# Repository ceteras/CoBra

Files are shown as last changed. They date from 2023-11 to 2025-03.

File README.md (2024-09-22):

# CoBra

CoBra is a Z80 computer designed in 1986 at ITCI, a research center in Brasov, Romania.  

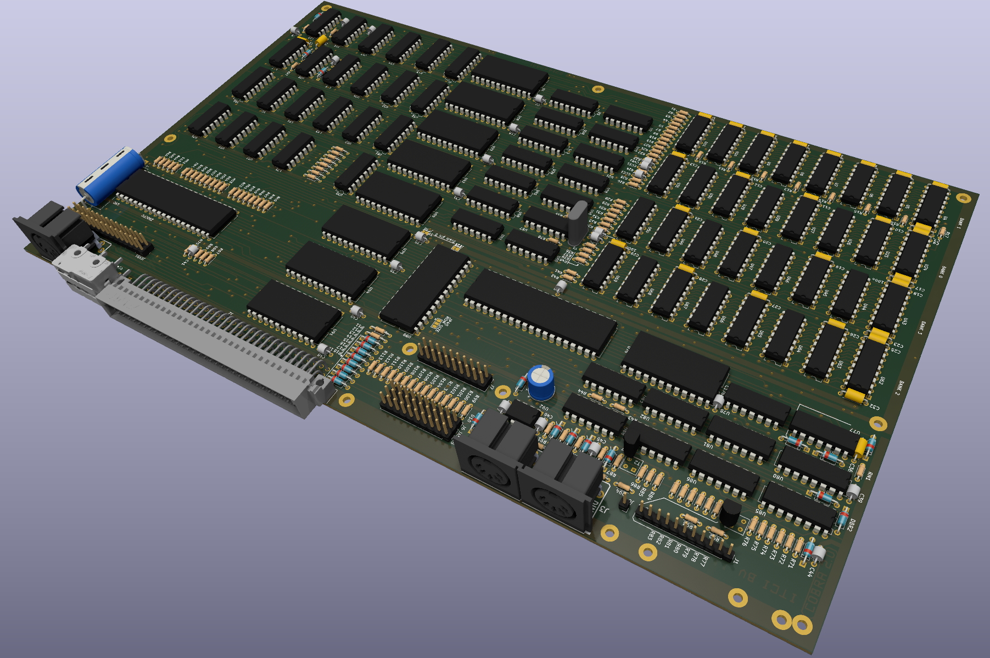
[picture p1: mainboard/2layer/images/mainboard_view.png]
CoBra mainboard


In its official version, its specs are:
- 3.5MHz Z80A CPU
- 64KB ram, made up of 4 banks of 8x 4116 chips each
- 2KB - 16KB ROM boot code (original firmware fits in 2K)
- 16KB ROM for the BASIC interpreter (8x 2716 or 4x 2732)
- 256 x 192 resolution ZX Spectrum video interface
- 58 keys keyboard, featuring 50 keys for ZX Spectrum mode plus 8 for CP/M
- i8272 floppy interface - on a daughter board (not included in the repo for now)
- RS232 port (bit-banged)
- joystick port
- 8 bit parallel port, input only, signals shared with the joystick interface
- extension port using a 3x32 pin DIN41612 connector

It's a two-in-one machine, it can be either a ZX Spectrum compatible or a CP/M machine.  
CoBra has three different memory maps: one for power-on, one for ZX Spectrum, and one for CP/M.  
The memory configuration change is done in software, using the bit 7 of the R register.  

On power-on, the memory map includes both ROMs, and RAM banks 0 and 1.  
Cobra boots from the small 2K ROM, it can display on the screen and copy code to RAM.  
Code can be copied from ROM for ZX Spectrum mode, and from the floppy interface for CP/M.  
Tape interface can also be an option, which should be great for development.  

After copying the code, it will switch the memory map to te desired architecture.  
ROMs are disabled now and execution continues from the 64KB of RAM.  

Many thanks to [cobrasov.com](https://cobrasov.com/CoBra%20Project/index.html), my main inspiration source in this endeavour.  
You can find out a lot about this incredible machine on the website, including many improvements made to the original boards by the community.  
Gerber files are also available there for these improved versions, all tested and working great!  

This repo is a "revival" approach, aiming to re-create the original computer in Kicad, adding only some minor tweaks.  
Current status: 
- the board is built (see bottom image), there were some pain points I should document here
- a floppy interface was also built, works with a modified BASIC (gerbers are Ver.1.2 on "Floppy" IF section on [cobrasov.com](https://cobrasov.com/CoBra%20Project/index.html).
- CP/M not possible to test yet, all versions I can get access to need a 80KB RAM upgrade.

Links:
- [2 Layer PCB project](https://github.com/ceteras/CoBra/tree/main/mainboard/2layer) - a 4 layer version is in the works too
- [Schematic in pdf format](https://github.com/ceteras/CoBra/blob/main/main.pdf)
- [Gerber files](https://github.com/ceteras/CoBra/tree/main/mainboard/2layer/kicad/fabrication)
- [Interactive BOM](https://github.com/ceteras/CoBra/blob/main/mainboard/2layer/kicad/bom/ibom.html)
- [A PAL encoder with S-Video connector](https://github.com/ceteras/CoBra/tree/main/s-video) - a draft, not tested yet
- [An USB keyboard adapter](https://github.com/ceteras/CoBra/tree/main/adapter/USB%20Keyboard) - this one is also not final, an experiment

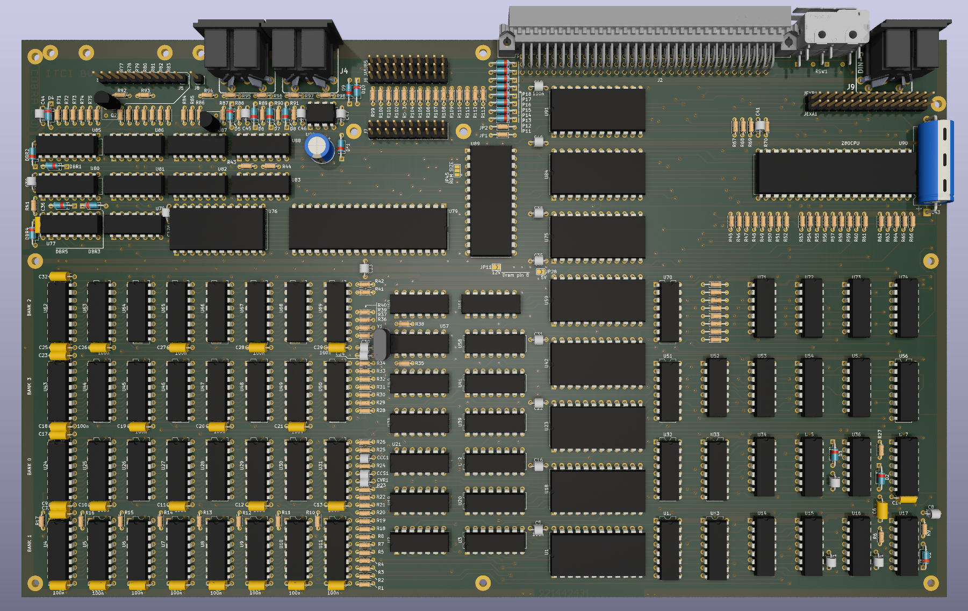
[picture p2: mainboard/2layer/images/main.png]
CoBra mainboard
 

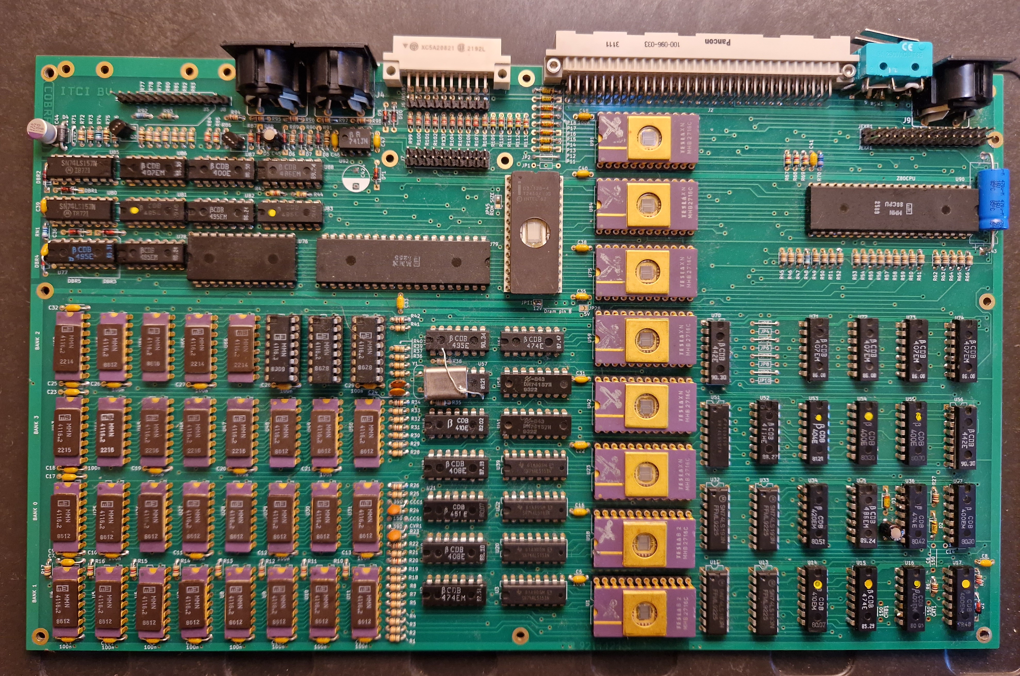
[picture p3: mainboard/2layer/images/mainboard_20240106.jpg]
Prototype


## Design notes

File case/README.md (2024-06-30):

# CoBra Case

The 3D modelling was done by [badrianiulian](https://github.com/badrianiulian).

The stl files can be used to order a 3D print, I chose PLA filament for my order, it came out ok, pictures below.

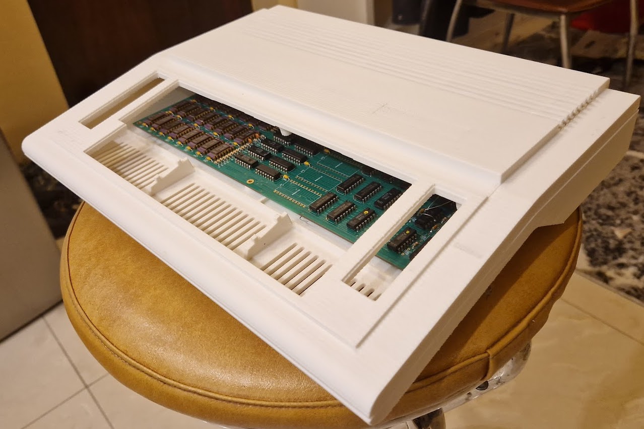
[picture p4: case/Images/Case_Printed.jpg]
  

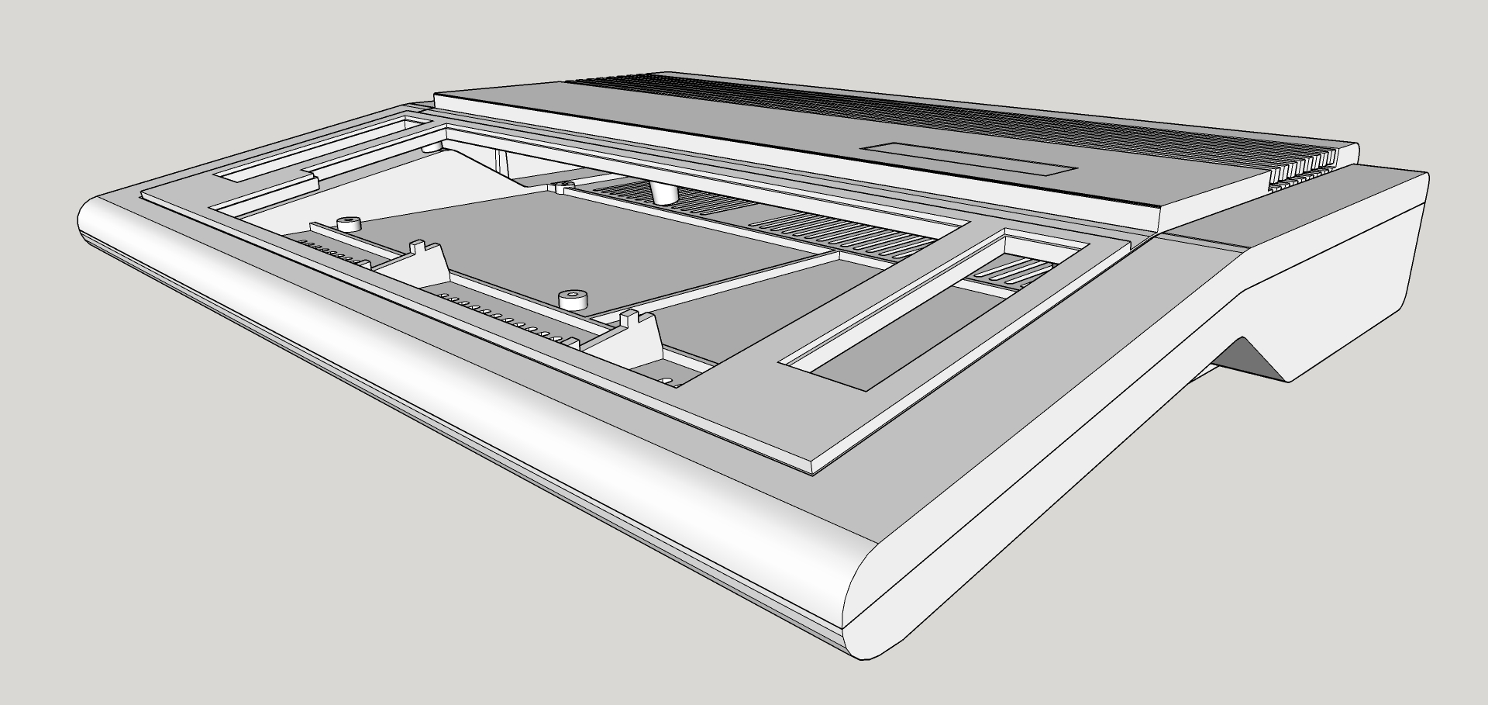
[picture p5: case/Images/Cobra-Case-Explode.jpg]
  

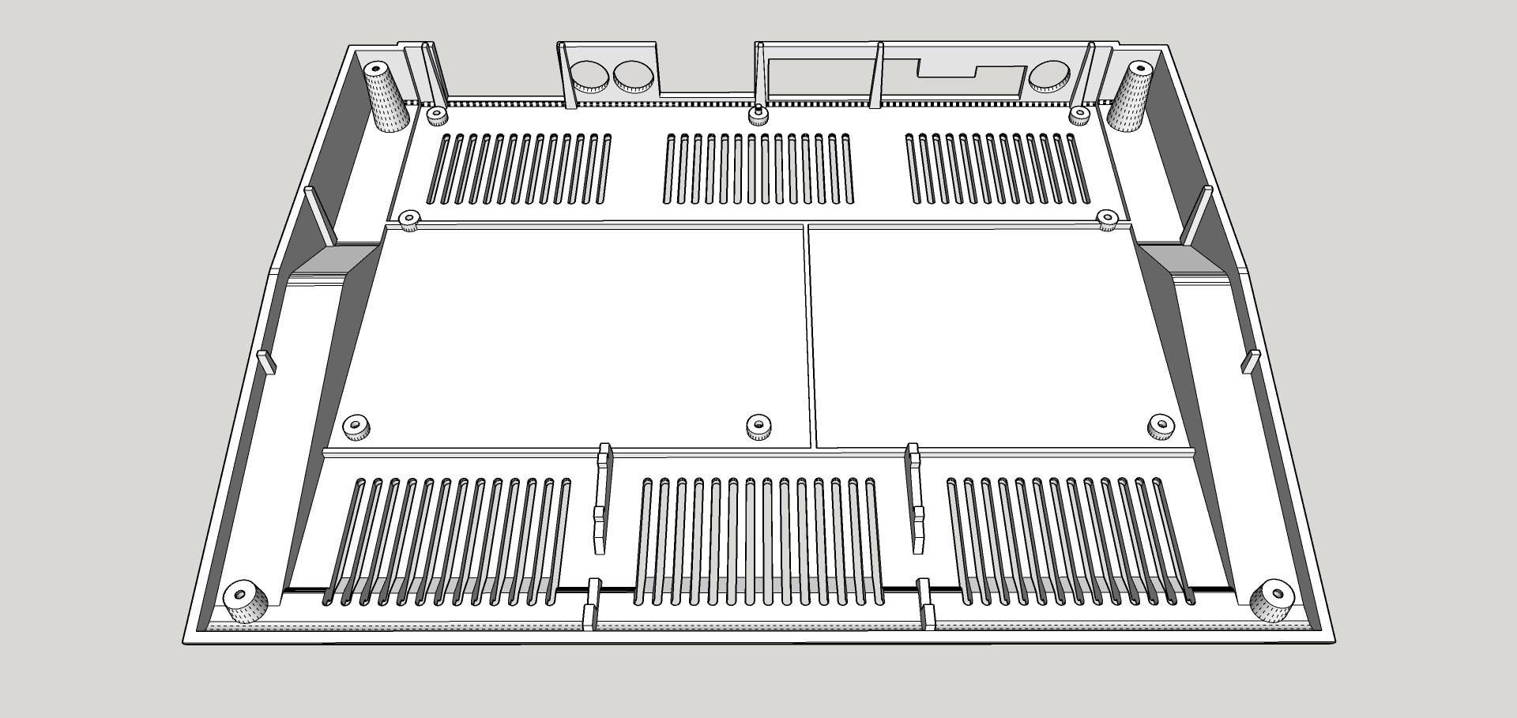
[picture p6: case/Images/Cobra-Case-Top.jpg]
  

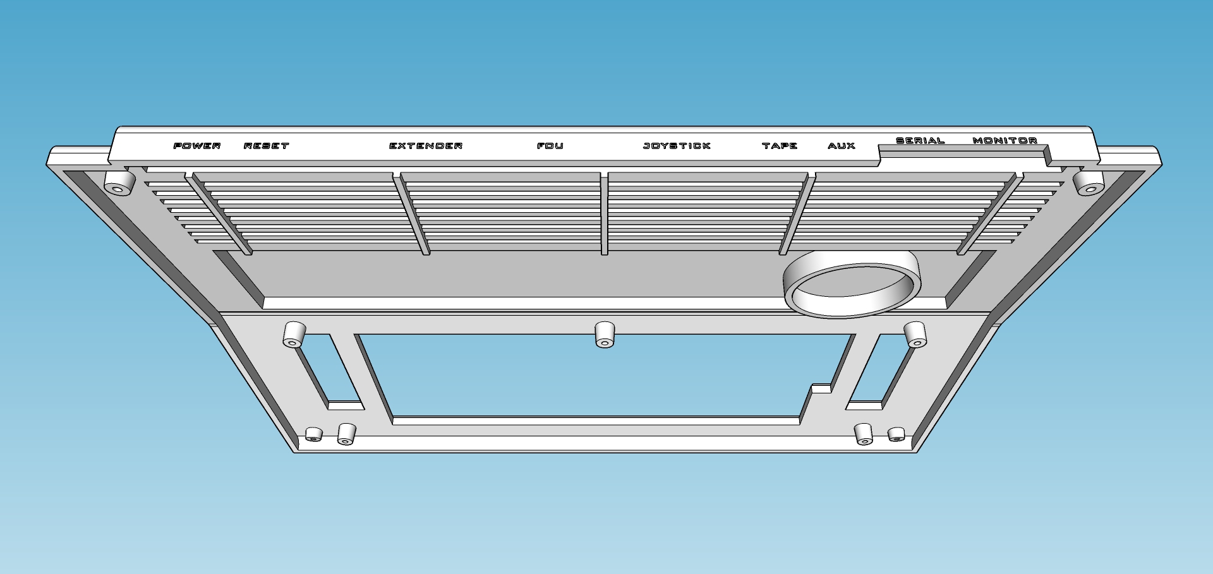
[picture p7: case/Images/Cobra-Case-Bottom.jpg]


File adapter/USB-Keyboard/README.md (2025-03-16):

# USB Keyboard Adapter (experimental)

Based on RP2040 Zero, emulates the CoBra switch matrix keyboard. 

The USB keyboard is connected to RP2040 USB port. Key codes are decoded and translated to an 8 byte array.
RP2040 reads the matrix column bus (KC[8..15] connected to A[8..15] through diodes) and sends the data  
corresponding to each key pressedi, from the array to the KR[0..5] bus.

Inputs to RP2040 are pulled high to 3.3V, so in theory this should be safe, as the 5V A[8..15] bus is behind reverse  
polarized diodes.  
Outputs are pulled high to 5V on the CoBra mainboard, hence the schottky diodes, for protection.
The keyboard input is an 8255 and its input voltage thresholds are safe for 3.3V logic (minimum 2V for input "1").

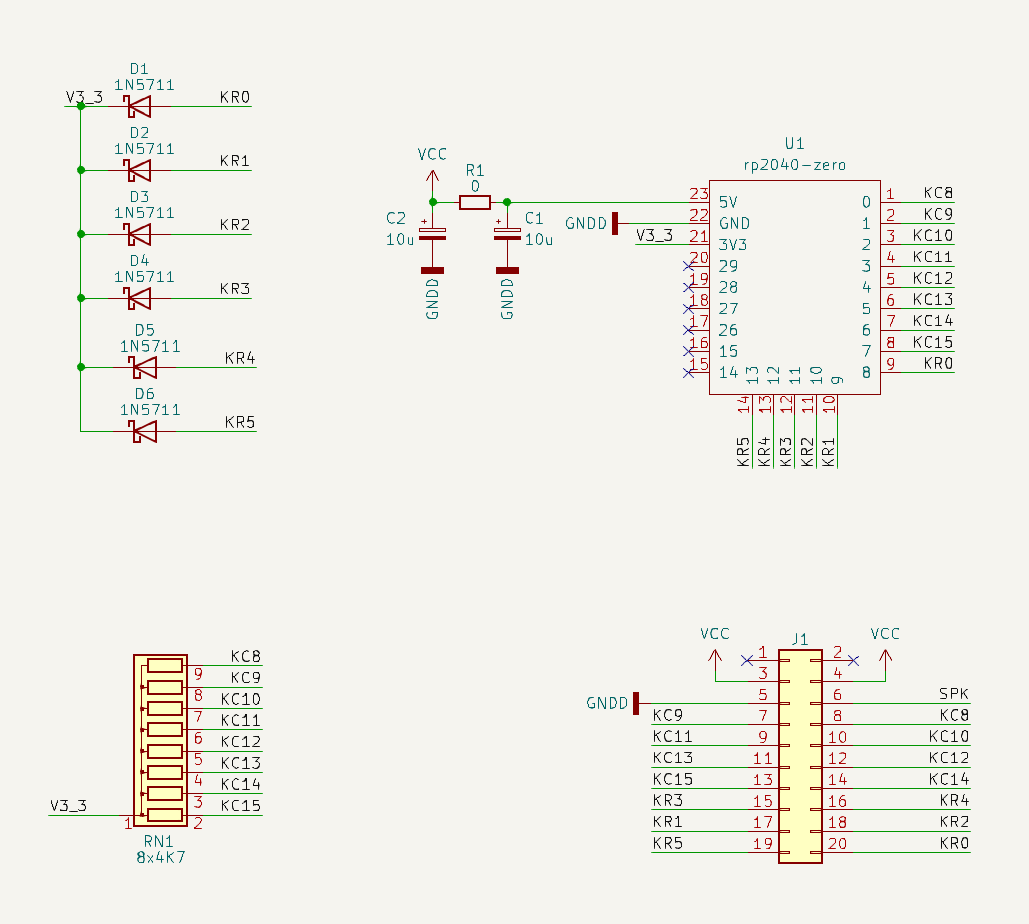
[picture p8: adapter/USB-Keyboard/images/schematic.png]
Adapter schematic


Key mapping:
- ALT / ALT gr - Symbol Shift
- GUI (Win key) - Caps Shift
- Cursor keys - CS + 5,6,7,8
- Backspace - CS + 0
- Insert - CS + 1 (edit)
- Application menu key - SS + X (pound)
- all symbols on a US keyboard [{]};:'"\|,<.>/?!@#$%^&*()_-+=   
  are mapped to their coreesponding CoBra key combinations  
  eg ")" - SS + 9, "~" - Extended mode + SS + A

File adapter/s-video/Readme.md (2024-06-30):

# S-Video Adapter for CoBra

Work in progress, untested.

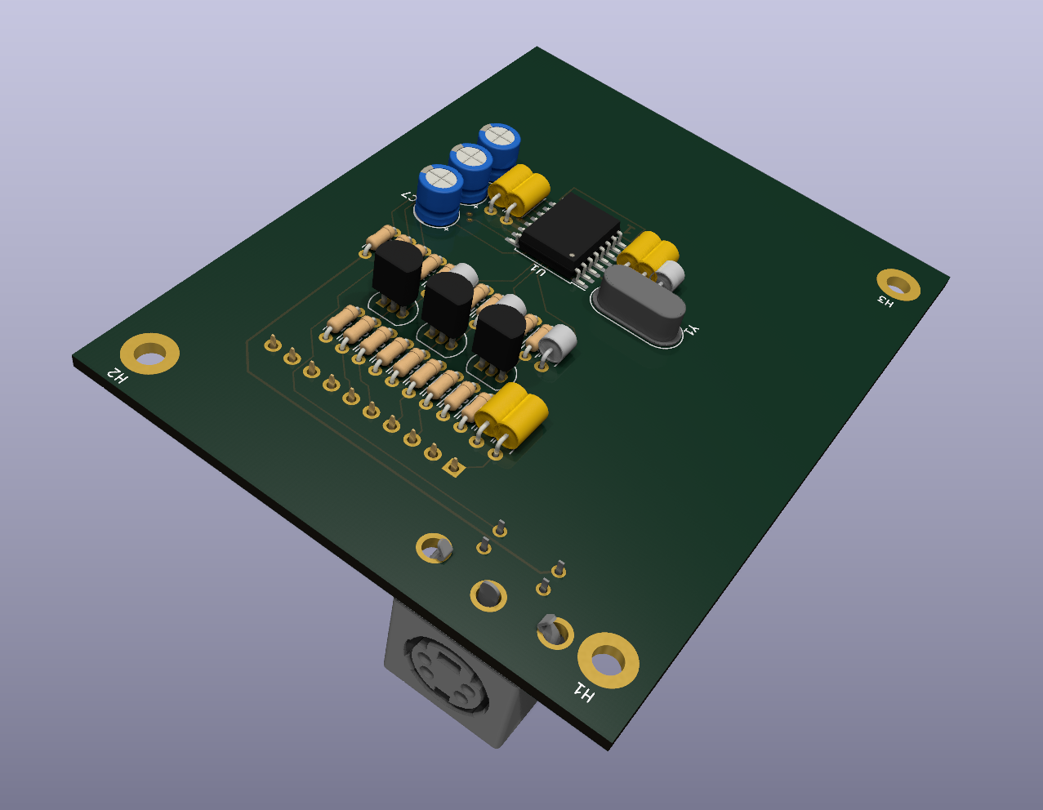
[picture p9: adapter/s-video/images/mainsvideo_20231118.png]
S-Video Adapter


This board is intended to connect to CoBra's video connector (J1).
It converts RGBI to PAL S-Video signals.

The schematic is inspired by [DonSuperfo's](https://github.com/DonSuperfo) [Superfo-Harlequin-128](https://github.com/DonSuperfo/Superfo-Harlequin-128).

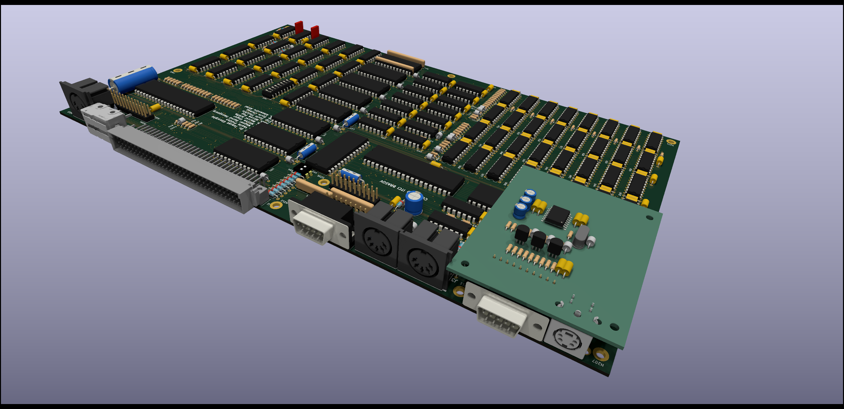
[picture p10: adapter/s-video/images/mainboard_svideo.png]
S-Video Adapter Installed


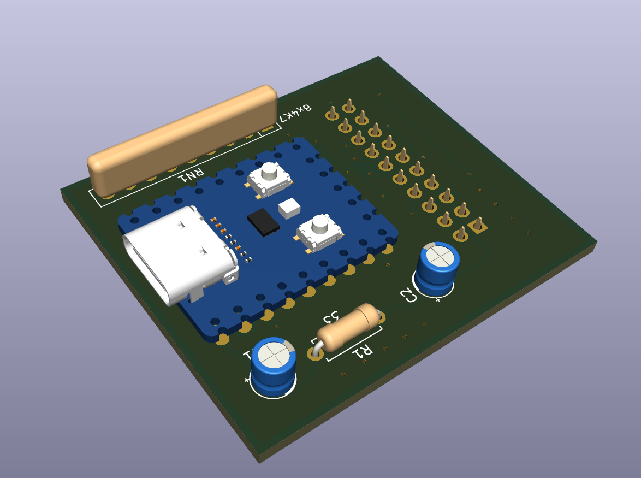
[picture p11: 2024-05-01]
adapter/USB-Keyboard/images/CObra_USB_KB_01.png

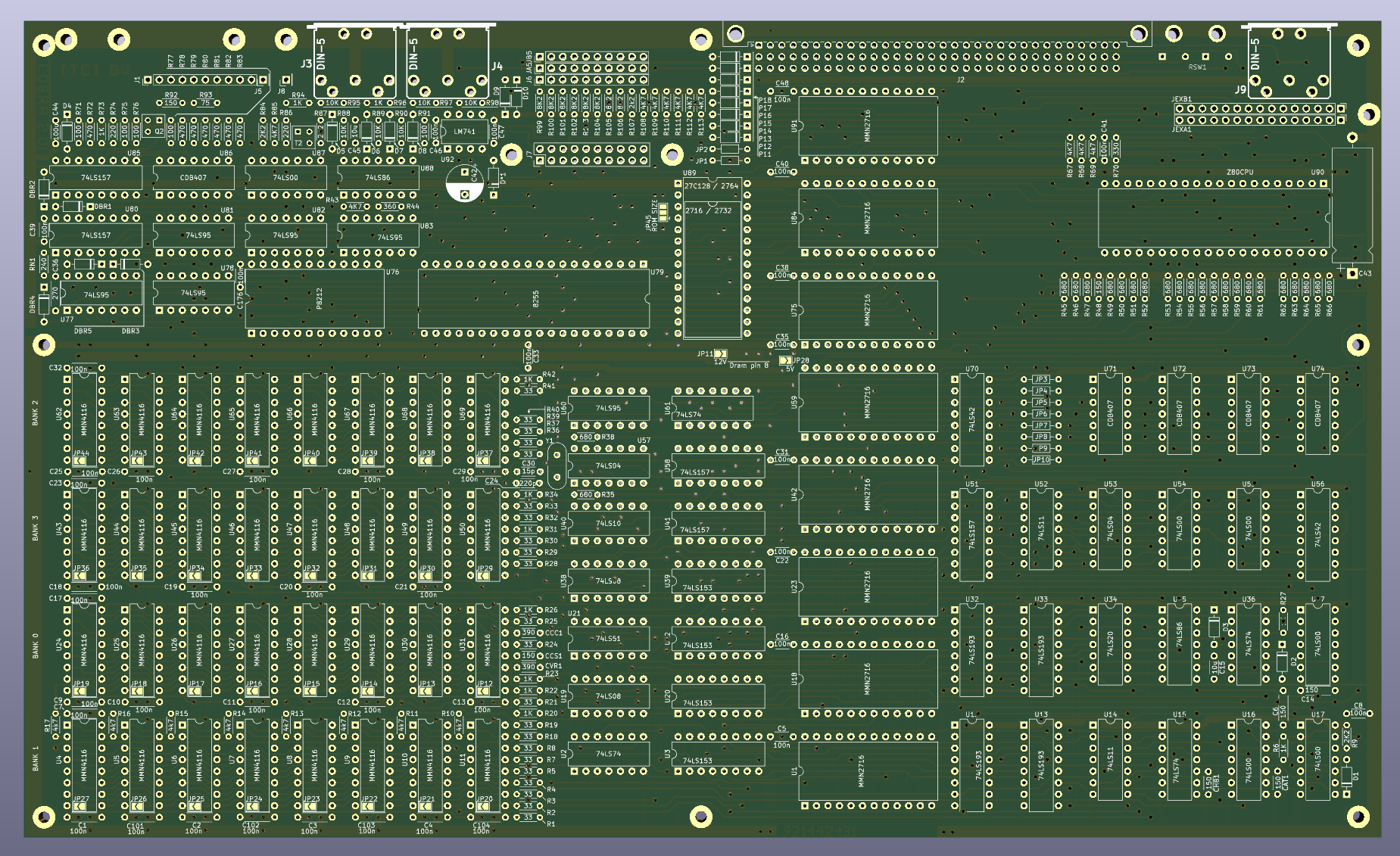
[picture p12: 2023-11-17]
mainboard/2layer/images/mainboard_no_tht.png

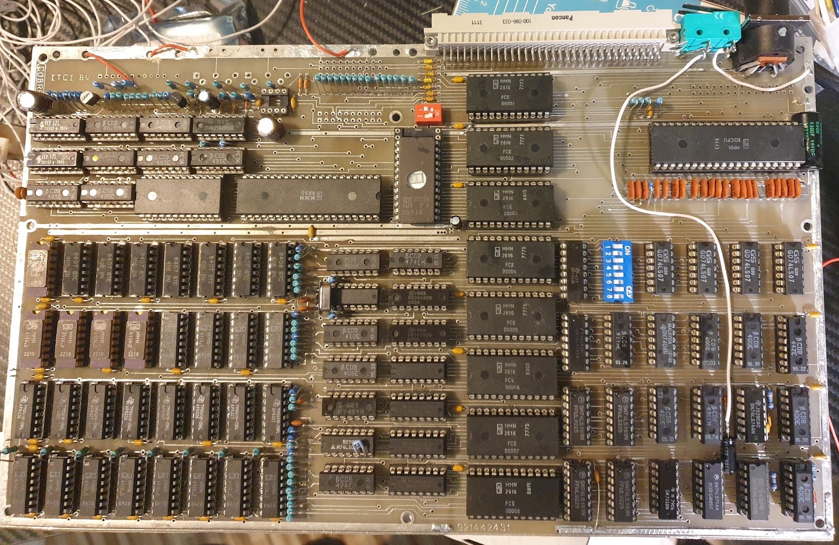
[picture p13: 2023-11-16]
mainboard/2layer/images/prototype.jpg

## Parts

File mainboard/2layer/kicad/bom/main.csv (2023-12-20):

Id | Designator | Footprint | Quantity | Designation | Supplier and ref
1 | R12,R69,R14,R17,R16,R15,R11,R13,R10 | R_Axial_DIN0204_L3.6mm_D1.6mm_P5.08mm_Horizontal | 9 | 4k7
2 | R68,R67,R43,R85,R108,R109,R110,R111,R112,R113 | R_Axial_DIN0204_L3.6mm_D1.6mm_P5.08mm_Horizontal | 10 | 4K7
3 | D2,D1,D3,D4,DBR1,DBR5,DBR4,DBR2,D6,D7,D9,D10,DBR3,P11,P12,P13,P14,P15,P16,P17,P18,D*1,D8 | D_DO-35_SOD27_P7.62mm_Horizontal | 23 | 1N4148
4 | C41,C16,C22,C31,C38,C40,C5,C48,C35,C39,C46,C176,C8,C47,C33 | C_THT_508_254 | 15 | 100n
5 | C23,C7,C32,C12,C13,C25,C21,C20,C26,C11,C29,C28,C27,C19,C10,C9,C2,C1,C3,C4,C17,C18,C104,C102,C101,C103 | C_THT_762_254 | 26 | 100n
6 | U86,U74,U73,U72,U71 | DIP-14_W7.62mm | 5 | CDB407
7 | U78,U77,U83,U81,U60,U82 | DIP-14_W7.62mm | 6 | 74LS95
8 | U80,U51,U41,U85,U58 | DIP-16_W7.62mm | 5 | 74LS157
9 | U88,U35 | DIP-14_W7.62mm | 2 | 74LS86
10 | U37,U17,U16,U54,U55,U87 | DIP-14_W7.62mm | 6 | 74LS00
11 | U52 | DIP-14_W7.62mm | 1 | 74LS11
12 | U36,U15,U2,U61 | DIP-14_W7.62mm | 4 | 74LS74
13 | U14,U40 | DIP-14_W7.62mm | 2 | 74LS10
14 | U76 | DIP-24_W15.24mm | 1 | P8212
15 | U90 | DIP-40_W15.24mm | 1 | Z80CPU
16 | U75,U59,U42,U18,U23,U1,U84,U91 | DIP-24_W15.24mm | 8 | MMN2716
17 | U68,U69,U67,U66,U64,U63,U46,U62,U50,U48,U45,U49,U47,U8,U31,U25,U10,U6,U65,U29,U9,U26,U43,U24,U44,U28,U30,U7,U27,U4,U11,U5 | DIP-16_W7.62mm | 32 | MMN4116
18 | U70,U56 | DIP-16_W7.62mm | 2 | 74LS42
19 | U57,U53 | DIP-14_W7.62mm | 2 | 74LS04
20 | U38,U19 | DIP-14_W7.62mm | 2 | 74LS08
21 | U33,U32,U12,U13 | DIP-16_W7.62mm | 4 | 74LS193
22 | U3,U20,U39,U22 | DIP-16_W7.62mm | 4 | 74LS153
23 | U21 | DIP-14_W7.62mm | 1 | 74LS51
24 | R54,R50,R66,R63,R55,R65,R62,R58,R51,R64,R61,R60,R56,R49,R46,R57,R45,R47,R53,R52,R59,R35,R38 | R_Axial_DIN0204_L3.6mm_D1.6mm_P5.08mm_Horizontal | 23 | 680
25 | R48,R92 | R_Axial_DIN0204_L3.6mm_D1.6mm_P5.08mm_Horizontal | 2 | 150
26 | JP1,JP3,JP5,JP7,JP9 | R_Axial_DIN0204_L3.6mm_D1.6mm_P7.62mm_Horizontal | 5 | Jumper_NC_Small
27 | JP6,JP4,JP10,JP8,JP2 | R_Axial_DIN0204_L3.6mm_D1.6mm_P7.62mm_Horizontal | 5 | Jumper_NO_Small
28 | U89 | DIP-28_W15.24mm | 1 | 27C128
29 | U34 | DIP-14_W7.62mm | 1 | 74LS20
30 | R72,R78,R79,R80,R81,R82,R83 | R_Axial_DIN0204_L3.6mm_D1.6mm_P5.08mm_Horizontal | 7 | 470
31 | R74,R86 | R_Axial_DIN0204_L3.6mm_D1.6mm_P5.08mm_Horizontal | 2 | 220
32 | R75,R76,R77,R71,R91 | R_Axial_DIN0204_L3.6mm_D1.6mm_P5.08mm_Horizontal | 5 | 100
33 | R93 | R_Axial_DIN0204_L3.6mm_D1.6mm_P5.08mm_Horizontal | 1 | 75
34 | R22,R73,R20,R23,R31,R34,R42,R96,R26,R27,R94,R6 | R_Axial_DIN0204_L3.6mm_D1.6mm_P5.08mm_Horizontal | 12 | 1K
35 | R2,R3,R4,R5,R1,R7,R8,R18,R19,R21,R24,R25,R32,R33,R41,R28,R29,R30,R36,R37,R39,R40 | R_Axial_DIN0204_L3.6mm_D1.6mm_P5.08mm_Horizontal | 22 | 33
36 | R70 | R_Axial_DIN0204_L3.6mm_D1.6mm_P5.08mm_Horizontal | 1 | 330
37 | R44 | R_Axial_DIN0204_L3.6mm_D1.6mm_P5.08mm_Horizontal | 1 | 360
38 | C42 | CP_Radial_D8.0mm_P5.00mm | 1 | 220u
39 | RN1 | R_Axial_DIN0204_L3.6mm_D1.6mm_P5.08mm_Horizontal | 1 | 240
40 | C14,C6 | C_THT_762_254 | 2 | 150
41 | R88,R89,R90,R95,R97,R98 | R_Axial_DIN0204_L3.6mm_D1.6mm_P5.08mm_Horizontal | 6 | 10K
42 | R84,R87,R9 | R_Axial_DIN0204_L3.6mm_D1.6mm_P5.08mm_Horizontal | 3 | 2K2
43 | Q2 | TO-92-Cobra | 1 | 2N2219
44 | J3,J4,J9 | DIN-5 | 3 | DIN-5
45 | U92 | DIP-8_W7.62mm | 1 | LM741
46 | CAT1,CHB1,CCS1 | C_THT_508_254 | 3 | 150
47 | J1,J6,JA5,JB5 | PinHeader_1x10_P2.54mm_Vertical | 4 | Conn_01x10
48 | C43 | CP_Axial_L25.0mm_D9.0mm_P30.00mm_Horizontal | 1 | 1500uF
49 | C24 | C_THT_508_254 | 1 | 220p
50 | C30 | C_THT_508_254 | 1 | 15p
51 | Y1 | Crystal_HC18-U_Vertical | 1 | 14MHz
52 | C44 | C_THT_508_254 | 1 | 100u
53 | C15,C45 | C_THT_508_254 | 2 | 10u
54 | C36 | C_THT_762_254 | 1 | 270
55 | CCC1,CVR1 | C_THT_508_254 | 2 | 390
56 | R106,R99,R100,R101,R102,R103,R104,R105 | R_Axial_DIN0204_L3.6mm_D1.6mm_P5.08mm_Horizontal | 8 | 8K2
57 | U79 | DIP-40_W15.24mm | 1 | 8255
58 | R107 | R_Axial_DIN0204_L3.6mm_D1.6mm_P5.08mm_Horizontal | 1 | 2k2
59 | D5 | D_DO-35_SOD27_P7.62mm_Horizontal | 1 | 4V7
60 | J2 | DIN41612_R_3x32_Male_Horizontal_THT | 1 | C96ABC
61 | JP35,JP32,JP14,JP44,JP12,JP40,JP26,JP24,JP11,JP15,JP17,JP18,JP43,JP23,JP31,JP38,JP29,JP34,JP33,JP13,JP30,JP28,JP37,JP42,JP27,JP16,JP21,JP22,JP36,JP41,JP19,JP39,JP20,JP25 | SolderJumper-2_P1.3mm_Open_TrianglePad1.0x1.5mm | 34 | SolderJumper_2_Open
62 | J7 | PinHeader_2x10_P2.54mm_Vertical | 1 | Conn_02x10_Odd_Even_MountingPin
63 | T2 | TO-92-CobraRev | 1 | BC327
64 | JP45 | SolderJumper-3_P1.3mm_Open_Pad1.0x1.5mm | 1 | SolderJumper_3_Open
65 | JEXA1,JEXB1 | PinHeader_1x15_P2.54mm_Vertical | 2 | Conn_01x15
66 | RSW1 | Reset_Switch | 1 | ~
67 | J8 | PinHeader_1x01_P2.54mm_Vertical | 1 | Conn_01x01_Male
68 | J5 | PinHeader_1x01_P2.54mm_Vertical | 1 | Conn_01x01_Male

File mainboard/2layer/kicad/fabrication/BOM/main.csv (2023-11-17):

Id | Designator | Footprint | Quantity | Designation | Supplier and ref
1 | R12,R69,R14,R17,R16,R15,R11,R13,R10 | R_Axial_DIN0204_L3.6mm_D1.6mm_P5.08mm_Horizontal | 9 | 4k7
2 | R68,R67,R43,R85,R108,R109,R110,R111,R112,R113 | R_Axial_DIN0204_L3.6mm_D1.6mm_P5.08mm_Horizontal | 10 | 4K7
3 | D2,D1,D3,D4,DBR1,DBR5,DBR4,DBR2,D6,D7,D9,D10,DBR3,P11,P12,P13,P14,P15,P16,P17,P18,D*1,D8 | D_DO-35_SOD27_P7.62mm_Horizontal | 23 | 1N4148
4 | C41,C16,C22,C31,C38,C40,C5,C48,C35,C39,C46,C176,C8,C47,C33 | C_THT_508_254 | 15 | 100n
5 | C23,C7,C32,C12,C13,C25,C21,C20,C26,C11,C29,C28,C27,C19,C10,C9,C2,C1,C3,C4,C17,C18,C104,C102,C101,C103 | C_THT_762_254 | 26 | 100n
6 | U86,U74,U73,U72,U71 | DIP-14_W7.62mm | 5 | CDB407
7 | U78,U77,U83,U81,U60,U82 | DIP-14_W7.62mm | 6 | 74LS95
8 | U80,U51,U41,U85,U58 | DIP-16_W7.62mm | 5 | 74LS157
9 | U88,U35 | DIP-14_W7.62mm | 2 | 74LS86
10 | U37,U17,U16,U54,U55,U87 | DIP-14_W7.62mm | 6 | 74LS00
11 | U52,U14 | DIP-14_W7.62mm | 2 | 74LS11
12 | U36,U15,U2,U61 | DIP-14_W7.62mm | 4 | 74LS74
13 | U76 | DIP-24_W15.24mm | 1 | P8212
14 | U90 | DIP-40_W15.24mm | 1 | Z80CPU
15 | U75,U59,U42,U18,U23,U1,U84,U91 | DIP-24_W15.24mm | 8 | MMN2716
16 | U68,U69,U67,U66,U64,U63,U46,U62,U50,U48,U45,U49,U47,U8,U31,U25,U10,U6,U65,U29,U9,U26,U43,U24,U44,U28,U30,U7,U27,U4,U11,U5 | DIP-16_W7.62mm | 32 | MMN4116
17 | U70,U56 | DIP-16_W7.62mm | 2 | 74LS42
18 | U57,U53 | DIP-14_W7.62mm | 2 | 74LS04
19 | U38,U19 | DIP-14_W7.62mm | 2 | 74LS08
20 | U33,U32,U12,U13 | DIP-16_W7.62mm | 4 | 74LS193
21 | U3,U20,U39,U22 | DIP-16_W7.62mm | 4 | 74LS153
22 | U21 | DIP-14_W7.62mm | 1 | 74LS51
23 | U40 | DIP-14_W7.62mm | 1 | 74LS10
24 | R54,R50,R66,R63,R55,R65,R62,R58,R51,R64,R61,R60,R56,R49,R46,R57,R45,R47,R53,R52,R59,R35,R38 | R_Axial_DIN0204_L3.6mm_D1.6mm_P5.08mm_Horizontal | 23 | 680
25 | R48,R92 | R_Axial_DIN0204_L3.6mm_D1.6mm_P5.08mm_Horizontal | 2 | 150
26 | JP1,JP3,JP5,JP7,JP9 | R_Axial_DIN0204_L3.6mm_D1.6mm_P7.62mm_Horizontal | 5 | Jumper_NC_Small
27 | JP6,JP4,JP10,JP8,JP2 | R_Axial_DIN0204_L3.6mm_D1.6mm_P7.62mm_Horizontal | 5 | Jumper_NO_Small
28 | U89 | DIP-28_W15.24mm | 1 | 27C128
29 | U34 | DIP-14_W7.62mm | 1 | 74LS20
30 | R72,R78,R79,R80,R81,R82,R83 | R_Axial_DIN0204_L3.6mm_D1.6mm_P5.08mm_Horizontal | 7 | 470
31 | R74,R86 | R_Axial_DIN0204_L3.6mm_D1.6mm_P5.08mm_Horizontal | 2 | 220
32 | R75,R76,R77,R71,R91 | R_Axial_DIN0204_L3.6mm_D1.6mm_P5.08mm_Horizontal | 5 | 100
33 | R93 | R_Axial_DIN0204_L3.6mm_D1.6mm_P5.08mm_Horizontal | 1 | 75
34 | R22,R73,R20,R23,R31,R34,R42,R96,R26,R27,R94,R6 | R_Axial_DIN0204_L3.6mm_D1.6mm_P5.08mm_Horizontal | 12 | 1K
35 | H1 | cobra_3.0_front_copper | 1 | front_CU
36 | R2,R3,R4,R5,R1,R7,R8,R18,R19,R21,R24,R25,R32,R33,R41,R28,R29,R30,R36,R37,R39,R40 | R_Axial_DIN0204_L3.6mm_D1.6mm_P5.08mm_Horizontal | 22 | 33
37 | R70 | R_Axial_DIN0204_L3.6mm_D1.6mm_P5.08mm_Horizontal | 1 | 330
38 | R44 | R_Axial_DIN0204_L3.6mm_D1.6mm_P5.08mm_Horizontal | 1 | 360
39 | C42 | CP_Radial_D8.0mm_P5.00mm | 1 | 220u
40 | RN1 | R_Axial_DIN0204_L3.6mm_D1.6mm_P5.08mm_Horizontal | 1 | 240
41 | C14,C6 | C_THT_762_254 | 2 | 150
42 | R88,R89,R90,R95,R97,R98 | R_Axial_DIN0204_L3.6mm_D1.6mm_P5.08mm_Horizontal | 6 | 10K
43 | R84,R87,R9 | R_Axial_DIN0204_L3.6mm_D1.6mm_P5.08mm_Horizontal | 3 | 2K2
44 | Q2 | TO-92-Cobra | 1 | 2N2219
45 | J3,J4,J9 | DIN-5 | 3 | DIN-5
46 | U92 | DIP-8_W7.62mm | 1 | LM741
47 | CAT1,CHB1,CCS1 | C_THT_508_254 | 3 | 150
48 | J1,J6,JA5,JB5 | PinHeader_1x10_P2.54mm_Vertical | 4 | Conn_01x10
49 | C43 | CP_Axial_L25.0mm_D9.0mm_P30.00mm_Horizontal | 1 | 1500uF
50 | H15,H5,H16,H17,H18,H21,H22,H24,H25,H8,H2,H4,H6 | MountingHole_2.5mm_Pad | 13 | MountingHole_Pad
51 | C24 | C_THT_508_254 | 1 | 220p
52 | C30 | C_THT_508_254 | 1 | 15p
53 | Y1 | Crystal_HC18-U_Vertical | 1 | 14MHz
54 | C44 | C_THT_508_254 | 1 | 100u
55 | H23,H7 | MountingHole_2.5mm_Pad | 2 | e
56 | H3 | cobra_3.0_back_copper | 1 | Back_CU
57 | C15,C45 | C_THT_508_254 | 2 | 10u
58 | C36 | C_THT_762_254 | 1 | 270
59 | CCC1,CVR1 | C_THT_508_254 | 2 | 390
60 | R106,R99,R100,R101,R102,R103,R104,R105 | R_Axial_DIN0204_L3.6mm_D1.6mm_P5.08mm_Horizontal | 8 | 8K2
61 | U79 | DIP-40_W15.24mm | 1 | 8255
62 | R107 | R_Axial_DIN0204_L3.6mm_D1.6mm_P5.08mm_Horizontal | 1 | 2k2
63 | D5 | D_DO-35_SOD27_P7.62mm_Horizontal | 1 | 4V7
64 | J2 | DIN41612_R_3x32_Male_Horizontal_THT | 1 | C96ABC
65 | JP35,JP32,JP14,JP44,JP12,JP40,JP26,JP24,JP11,JP15,JP17,JP18,JP43,JP23,JP31,JP38,JP29,JP34,JP33,JP13,JP30,JP28,JP37,JP42,JP27,JP16,JP21,JP22,JP36,JP41,JP19,JP39,JP20,JP25 | SolderJumper-2_P1.3mm_Open_TrianglePad1.0x1.5mm | 34 | SolderJumper_2_Open
66 | J7 | PinHeader_2x10_P2.54mm_Vertical | 1 | Conn_02x10_Odd_Even_MountingPin
67 | T2 | TO-92-CobraRev | 1 | BC327
68 | JP45 | SolderJumper-3_P1.3mm_Open_Pad1.0x1.5mm | 1 | SolderJumper_3_Open
69 | JEXA1,JEXB1 | PinHeader_1x15_P2.54mm_Vertical | 2 | Conn_01x15
70 | RSW1 | Reset_Switch | 1 | ~
71 | J8 | PinHeader_1x01_P2.54mm_Vertical | 1 | Conn_01x01_Male
72 | J5 | PinHeader_1x01_P2.54mm_Vertical | 1 | Conn_01x01_Male

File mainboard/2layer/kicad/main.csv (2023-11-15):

Reference | Value | Footprint | Datasheet
U79 | 8255 | Package_DIP:DIP-40_W15.24mm | http://aturing.umcs.maine.edu/~meadow/courses/cos335/Intel8255A.pdf
U53 | 74LS04 | Package_DIP:DIP-14_W7.62mm | http://www.ti.com/lit/gpn/sn74LS04
U54 | 74LS00 | Package_DIP:DIP-14_W7.62mm | http://www.ti.com/lit/gpn/sn74ls00
U35 | 74LS86 | Package_DIP:DIP-14_W7.62mm | 74xx/74ls86.pdf
C33 | 100n | Capacitor_THT:C_Rect_L4.6mm_W2.0mm_P2.50mm_MKS02_FKP02 | ~
R99 | 8K2 |  | ~
R100 | 8K2 |  | ~
R101 | 8K2 |  | ~
R102 | 8K2 |  | ~
R103 | 8K2 |  | ~
R104 | 8K2 |  | ~
R105 | 8K2 |  | ~
R106 | 8K2 |  | ~
U90 | Z80CPU | Package_DIP:DIP-40_W15.24mm | www.zilog.com/manage_directlink.php?filepath=docs/z80/um0080
C41 | 100n | Capacitor_THT:C_Rect_L7.0mm_W2.0mm_P5.00mm | ~
U73 | CDB407 | Package_DIP:DIP-14_W7.62mm_LongPads
U71 | CDB407 | Package_DIP:DIP-14_W7.62mm_LongPads
U74 | CDB407 | Package_DIP:DIP-14_W7.62mm_LongPads
R70 | 330 | Resistor_THT:R_Axial_DIN0204_L3.6mm_D1.6mm_P5.08mm_Horizontal | ~
R56 | 680 | Resistor_THT:R_Axial_DIN0204_L3.6mm_D1.6mm_P5.08mm_Horizontal | ~
R57 | 680 | Resistor_THT:R_Axial_DIN0204_L3.6mm_D1.6mm_P5.08mm_Horizontal | ~
R58 | 680 | Resistor_THT:R_Axial_DIN0204_L3.6mm_D1.6mm_P5.08mm_Horizontal | ~
R59 | 680 | Resistor_THT:R_Axial_DIN0204_L3.6mm_D1.6mm_P5.08mm_Horizontal | ~
R60 | 680 | Resistor_THT:R_Axial_DIN0204_L3.6mm_D1.6mm_P5.08mm_Horizontal | ~
R52 | 680 | Resistor_THT:R_Axial_DIN0204_L3.6mm_D1.6mm_P5.08mm_Horizontal | ~
R61 | 680 | Resistor_THT:R_Axial_DIN0204_L3.6mm_D1.6mm_P5.08mm_Horizontal | ~
R62 | 680 | Resistor_THT:R_Axial_DIN0204_L3.6mm_D1.6mm_P5.08mm_Horizontal | ~
R63 | 680 | Resistor_THT:R_Axial_DIN0204_L3.6mm_D1.6mm_P5.08mm_Horizontal | ~
R64 | 680 | Resistor_THT:R_Axial_DIN0204_L3.6mm_D1.6mm_P5.08mm_Horizontal | ~
R65 | 680 | Resistor_THT:R_Axial_DIN0204_L3.6mm_D1.6mm_P5.08mm_Horizontal | ~
R66 | 680 | Resistor_THT:R_Axial_DIN0204_L3.6mm_D1.6mm_P5.08mm_Horizontal | ~
R51 | 680 | Resistor_THT:R_Axial_DIN0204_L3.6mm_D1.6mm_P5.08mm_Horizontal | ~
R55 | 680 | Resistor_THT:R_Axial_DIN0204_L3.6mm_D1.6mm_P5.08mm_Horizontal | ~
R50 | 680 | Resistor_THT:R_Axial_DIN0204_L3.6mm_D1.6mm_P5.08mm_Horizontal | ~
R45 | 680 | Resistor_THT:R_Axial_DIN0204_L3.6mm_D1.6mm_P5.08mm_Horizontal | ~
R53 | 680 | Resistor_THT:R_Axial_DIN0204_L3.6mm_D1.6mm_P5.08mm_Horizontal | ~
R54 | 680 | Resistor_THT:R_Axial_DIN0204_L3.6mm_D1.6mm_P5.08mm_Horizontal | ~
R47 | 680 | Resistor_THT:R_Axial_DIN0204_L3.6mm_D1.6mm_P5.08mm_Horizontal | ~
R46 | 680 | Resistor_THT:R_Axial_DIN0204_L3.6mm_D1.6mm_P5.08mm_Horizontal | ~
R48 | 680 | Resistor_THT:R_Axial_DIN0204_L3.6mm_D1.6mm_P5.08mm_Horizontal | ~
R49 | 680 | Resistor_THT:R_Axial_DIN0204_L3.6mm_D1.6mm_P5.08mm_Horizontal | ~
R68 | 680 | Resistor_THT:R_Axial_DIN0204_L3.6mm_D1.6mm_P5.08mm_Horizontal | ~
R67 | 680 | Resistor_THT:R_Axial_DIN0204_L3.6mm_D1.6mm_P5.08mm_Horizontal | ~
R69 | 4k7 | Resistor_THT:R_Axial_DIN0204_L3.6mm_D1.6mm_P5.08mm_Horizontal | ~
R10 | 4k7 | Resistor_THT:R_Axial_DIN0204_L3.6mm_D1.6mm_P5.08mm_Horizontal | ~
R11 | 4k7 | Resistor_THT:R_Axial_DIN0204_L3.6mm_D1.6mm_P5.08mm_Horizontal | ~
R12 | 4k7 | Resistor_THT:R_Axial_DIN0204_L3.6mm_D1.6mm_P5.08mm_Horizontal | ~
R13 | 4k7 | Resistor_THT:R_Axial_DIN0204_L3.6mm_D1.6mm_P5.08mm_Horizontal | ~
R14 | 4k7 | Resistor_THT:R_Axial_DIN0204_L3.6mm_D1.6mm_P5.08mm_Horizontal | ~
R15 | 4k7 | Resistor_THT:R_Axial_DIN0204_L3.6mm_D1.6mm_P5.08mm_Horizontal | ~
R16 | 4k7 | Resistor_THT:R_Axial_DIN0204_L3.6mm_D1.6mm_P5.08mm_Horizontal | ~
R17 | 4k7 | Resistor_THT:R_Axial_DIN0204_L3.6mm_D1.6mm_P5.08mm_Horizontal | ~
U72 | CDB407 | Package_DIP:DIP-14_W7.62mm_LongPads
SW_CS1 | SW_Push |  | ~
SW_A1 | SW_Push |  | ~
SW_Q1 | SW_Push |  | ~
SW_1 | SW_Push |  | ~
SW_0 | SW_Push |  | ~
SW_P1 | SW_Push |  | ~
SW_ENT1 | SW_Push |  | ~
SW_SP1 | SW_Push |  | ~
SW_Z1 | SW_Push |  | ~
SW_S1 | SW_Push |  | ~
SW_W1 | SW_Push |  | ~
SW_2 | SW_Push |  | ~
SW_9 | SW_Push |  | ~
SW_O1 | SW_Push |  | ~
SW_L1 | SW_Push |  | ~
SW_SS1 | SW_Push |  | ~
SW_X1 | SW_Push |  | ~
SW_D1 | SW_Push |  | ~
SW_E1 | SW_Push |  | ~
SW_3 | SW_Push |  | ~
SW_8 | SW_Push |  | ~
SW_I1 | SW_Push |  | ~
SW_K1 | SW_Push |  | ~
SW_M1 | SW_Push |  | ~
SW_C1 | SW_Push |  | ~
SW_F5 | SW_Push |  | ~
SW_R1 | SW_Push |  | ~
SW_4 | SW_Push |  | ~
SW_7 | SW_Push |  | ~
SW_U1 | SW_Push |  | ~
SW_J1 | SW_Push |  | ~
SW_N1 | SW_Push |  | ~
SW_V1 | SW_Push |  | ~
SW_G1 | SW_Push |  | ~
SW_T1 | SW_Push |  | ~
SW_5 | SW_Push |  | ~
SW_6 | SW_Push |  | ~
SW_Y1 | SW_Push |  | ~
SW_H1 | SW_Push |  | ~
SW_B1 | SW_Push |  | ~
D11 | 1N4148 | Diode_THT:D_DO-35_SOD27_P7.62mm_Horizontal | https://assets.nexperia.com/documents/data-sheet/1N4148_1N4448.pdf
D12 | 1N4148 | Diode_THT:D_DO-35_SOD27_P7.62mm_Horizontal | https://assets.nexperia.com/documents/data-sheet/1N4148_1N4448.pdf
D13 | 1N4148 | Diode_THT:D_DO-35_SOD27_P7.62mm_Horizontal | https://assets.nexperia.com/documents/data-sheet/1N4148_1N4448.pdf
D14 | 1N4148 | Diode_THT:D_DO-35_SOD27_P7.62mm_Horizontal | https://assets.nexperia.com/documents/data-sheet/1N4148_1N4448.pdf
D15 | 1N4148 | Diode_THT:D_DO-35_SOD27_P7.62mm_Horizontal | https://assets.nexperia.com/documents/data-sheet/1N4148_1N4448.pdf
D16 | 1N4148 | Diode_THT:D_DO-35_SOD27_P7.62mm_Horizontal | https://assets.nexperia.com/documents/data-sheet/1N4148_1N4448.pdf
D17 | 1N4148 | Diode_THT:D_DO-35_SOD27_P7.62mm_Horizontal | https://assets.nexperia.com/documents/data-sheet/1N4148_1N4448.pdf
D18 | 1N4148 | Diode_THT:D_DO-35_SOD27_P7.62mm_Horizontal | https://assets.nexperia.com/documents/data-sheet/1N4148_1N4448.pdf
R109 | R_Small |  | ~
R110 | R_Small |  | ~
R111 | R_Small |  | ~
R112 | R_Small |  | ~
R113 | R_Small |  | ~
SW_CTRL1 | SW_Push |  | ~
SW_NO_SCR1 | SW_Push |  | ~
SW_LF1 | SW_Push |  | ~
SW_ESC1 | SW_Push |  | ~
SW_F1 | SW_Push |  | ~
SW_F2 | SW_Push |  | ~
SW_F3 | SW_Push |  | ~
SW_F4 | SW_Push |  | ~
R108 | R_Small |  | ~
QK1 | 2N3904 | Package_TO_SOT_THT:TO-92_Inline | https://www.onsemi.com/pub/Collateral/2N3903-D.PDF
DK9 | 1N4148 | Diode_THT:D_DO-35_SOD27_P7.62mm_Horizontal | https://assets.nexperia.com/documents/data-sheet/1N4148_1N4448.pdf
DK12 | 1N4148 | Diode_THT:D_DO-35_SOD27_P7.62mm_Horizontal | https://assets.nexperia.com/documents/data-sheet/1N4148_1N4448.pdf
QK5 | 2N3904 | Package_TO_SOT_THT:TO-92_Inline | https://www.onsemi.com/pub/Collateral/2N3903-D.PDF
DK15 | 1N4148 | Diode_THT:D_DO-35_SOD27_P7.62mm_Horizontal | https://assets.nexperia.com/documents/data-sheet/1N4148_1N4448.pdf
QK9 | 2N3904 | Package_TO_SOT_THT:TO-92_Inline | https://www.onsemi.com/pub/Collateral/2N3903-D.PDF
SW_LEFT1 | SW_Push |  | ~
SW_DOWN1 | SW_Push |  | ~
SW_DOWN2 | SW_Push |  | ~
RK8 | R_Small |  | ~
QK2 | 2N3904 | Package_TO_SOT_THT:TO-92_Inline | https://www.onsemi.com/pub/Collateral/2N3903-D.PDF
DK10 | 1N4148 | Diode_THT:D_DO-35_SOD27_P7.62mm_Horizontal | https://assets.nexperia.com/documents/data-sheet/1N4148_1N4448.pdf
DK13 | 1N4148 | Diode_THT:D_DO-35_SOD27_P7.62mm_Horizontal | https://assets.nexperia.com/documents/data-sheet/1N4148_1N4448.pdf
QK6 | 2N3904 | Package_TO_SOT_THT:TO-92_Inline | https://www.onsemi.com/pub/Collateral/2N3903-D.PDF
DK16 | 1N4148 | Diode_THT:D_DO-35_SOD27_P7.62mm_Horizontal | https://assets.nexperia.com/documents/data-sheet/1N4148_1N4448.pdf
QK10 | 2N3904 | Package_TO_SOT_THT:TO-92_Inline | https://www.onsemi.com/pub/Collateral/2N3903-D.PDF
SW_RIGHT1 | SW_Push |  | ~
SW_CS_LK1 | SW_Push |  | ~
SW_GRAPH1 | SW_Push |  | ~
QK3 | 2N3904 | Package_TO_SOT_THT:TO-92_Inline | https://www.onsemi.com/pub/Collateral/2N3903-D.PDF
DK11 | 1N4148 | Diode_THT:D_DO-35_SOD27_P7.62mm_Horizontal | https://assets.nexperia.com/documents/data-sheet/1N4148_1N4448.pdf
DK14 | 1N4148 | Diode_THT:D_DO-35_SOD27_P7.62mm_Horizontal | https://assets.nexperia.com/documents/data-sheet/1N4148_1N4448.pdf
QK7 | 2N3904 | Package_TO_SOT_THT:TO-92_Inline | https://www.onsemi.com/pub/Collateral/2N3903-D.PDF
DK17 | 1N4148 | Diode_THT:D_DO-35_SOD27_P7.62mm_Horizontal | https://assets.nexperia.com/documents/data-sheet/1N4148_1N4448.pdf
QK11 | 2N3904 | Package_TO_SOT_THT:TO-92_Inline | https://www.onsemi.com/pub/Collateral/2N3903-D.PDF
SW_NEW_M1 | SW_Push |  | ~
SW_PG_ED1 | SW_Push |  | ~
SW_DEL1 | SW_Push |  | ~
QK4 | 2N3904 | Package_TO_SOT_THT:TO-92_Inline | https://www.onsemi.com/pub/Collateral/2N3903-D.PDF
RK9 | 4K7 |  | ~
CK2 | 10U |  | ~
SW_NEW_M2 | SW_Push |  | ~
RK11 | 10K |  | ~
CK3 | 10U |  | ~
RK12 | 4K7 |  | ~
QK8 | 2N3904 | Package_TO_SOT_THT:TO-92_Inline | https://www.onsemi.com/pub/Collateral/2N3903-D.PDF
J1001 | Motherboard |  | ~
J7 | Keyboard |  | ~
LS1 | Speaker |  | ~
RK10 | 4K7 |  | ~
U56 | 74LS42 | Package_DIP:DIP-16_W7.62mm | http://www.ti.com/lit/gpn/sn74LS42
U52 | 74LS11 | Package_DIP:DIP-14_W7.62mm | http://www.ti.com/lit/gpn/sn74LS11
U55 | 74LS00 | Package_DIP:DIP-14_W7.62mm | http://www.ti.com/lit/gpn/sn74ls00
U17 | 74LS00 | Package_DIP:DIP-14_W7.62mm | http://www.ti.com/lit/gpn/sn74ls00
D1 | 1N4148 | Diode_THT:D_DO-35_SOD27_P7.62mm_Horizontal | https://assets.nexperia.com/documents/data-sheet/1N4148_1N4448.pdf
D2 | 1N4148 | Diode_THT:D_DO-35_SOD27_P7.62mm_Horizontal | https://assets.nexperia.com/documents/data-sheet/1N4148_1N4448.pdf
R1300 | R |  | ~
R9 | 2K2 |  | ~
U36 | 74LS74 | Package_DIP:DIP-14_W7.62mm | 74xx/74hc_hct74.pdf
R27 | 1K |  | ~
C900 | C |  | ~
C15 | 10 |  | ~
D3 | 1N4148 | Diode_THT:D_DO-35_SOD27_P7.62mm_Horizontal | https://assets.nexperia.com/documents/data-sheet/1N4148_1N4448.pdf
U19 | 74LS08 | Package_DIP:DIP-14_W7.62mm | http://www.ti.com/lit/gpn/sn74LS08
U16 | 74LS00 | Package_DIP:DIP-14_W7.62mm | http://www.ti.com/lit/gpn/sn74ls00
U37 | 74LS00 | Package_DIP:DIP-14_W7.62mm | http://www.ti.com/lit/gpn/sn74ls00
U14 | 74LS11 | Package_DIP:DIP-14_W7.62mm | http://www.ti.com/lit/gpn/sn74LS11
C6 | C |  | ~
U34 | 74LS20 | Package_DIP:DIP-14_W7.62mm | http://www.ti.com/lit/gpn/sn74LS20
C14 | C_Small |  | ~
SW1 | SW_RSB |  | ~
SW2 | SW_RST |  | ~
CHB1 | 150p |  | ~
CAT1 | C_Small |  | ~
U91 | MMN2716 | Package_DIP:DIP-24_W15.24mm
U42 | MMN2716 | Package_DIP:DIP-24_W15.24mm
JP1 | Jumper_NC_Small | Resistor_THT:R_Axial_DIN0204_L3.6mm_D1.6mm_P7.62mm_Horizontal | ~
JP2 | Jumper_NO_Small | Resistor_THT:R_Axial_DIN0204_L3.6mm_D1.6mm_P7.62mm_Horizontal | ~
JP3 | Jumper_NC_Small | Resistor_THT:R_Axial_DIN0204_L3.6mm_D1.6mm_P7.62mm_Horizontal | ~
JP4 | Jumper_NO_Small | Resistor_THT:R_Axial_DIN0204_L3.6mm_D1.6mm_P7.62mm_Horizontal | ~
JP5 | Jumper_NC_Small | Resistor_THT:R_Axial_DIN0204_L3.6mm_D1.6mm_P7.62mm_Horizontal | ~
JP6 | Jumper_NO_Small | Resistor_THT:R_Axial_DIN0204_L3.6mm_D1.6mm_P7.62mm_Horizontal | ~
JP7 | Jumper_NC_Small | Resistor_THT:R_Axial_DIN0204_L3.6mm_D1.6mm_P7.62mm_Horizontal | ~
JP8 | Jumper_NO_Small | Resistor_THT:R_Axial_DIN0204_L3.6mm_D1.6mm_P7.62mm_Horizontal | ~
JP9 | Jumper_NC_Small | Resistor_THT:R_Axial_DIN0204_L3.6mm_D1.6mm_P7.62mm_Horizontal | ~
JP10 | Jumper_NO_Small | Resistor_THT:R_Axial_DIN0204_L3.6mm_D1.6mm_P7.62mm_Horizontal | ~
U70 | 74LS42 | Package_DIP:DIP-16_W7.62mm | http://www.ti.com/lit/gpn/sn74LS42
U1 | MMN2716 | Package_DIP:DIP-24_W15.24mm
U18 | MMN2716 | Package_DIP:DIP-24_W15.24mm
U23 | MMN2716 | Package_DIP:DIP-24_W15.24mm
U59 | MMN2716 | Package_DIP:DIP-24_W15.24mm
U75 | MMN2716 | Package_DIP:DIP-24_W15.24mm
U84 | MMN2716 | Package_DIP:DIP-24_W15.24mm
C31 | C_Small | Capacitor_THT:C_Rect_L7.0mm_W2.0mm_P5.00mm | ~
C22 | C_Small | Capacitor_THT:C_Rect_L7.0mm_W2.0mm_P5.00mm | ~
C16 | C_Small | Capacitor_THT:C_Rect_L7.0mm_W2.0mm_P5.00mm | ~
C5 | C_Small | Capacitor_THT:C_Rect_L7.0mm_W2.0mm_P5.00mm | ~
C35 | C_Small | Capacitor_THT:C_Rect_L7.0mm_W2.0mm_P5.00mm | ~
C38 | 100n | Capacitor_THT:C_Rect_L7.0mm_W2.0mm_P5.00mm | ~
C40 | C_Small | Capacitor_THT:C_Rect_L7.0mm_W2.0mm_P5.00mm | ~
C48 | C_Small | Capacitor_THT:C_Rect_L7.0mm_W2.0mm_P5.00mm | ~
U89 | 27C128 | Package_DIP:DIP-28_W15.24mm | http://ww1.microchip.com/downloads/en/devicedoc/11003L.pdf
U62 | MMN4116 | Package_DIP:DIP-16_W7.62mm
C25 | C_Small | Capacitor_THT:C_Rect_L9.0mm_W2.5mm_P7.50mm_MKT | ~
U63 | MMN4116 | Package_DIP:DIP-16_W7.62mm
U64 | MMN4116 | Package_DIP:DIP-16_W7.62mm
U65 | MMN4116 | Package_DIP:DIP-16_W7.62mm
U66 | MMN4116 | Package_DIP:DIP-16_W7.62mm
U67 | MMN4116 | Package_DIP:DIP-16_W7.62mm
U68 | MMN4116 | Package_DIP:DIP-16_W7.62mm
U69 | MMN4116 | Package_DIP:DIP-16_W7.62mm
U43 | MMN4116 | Package_DIP:DIP-16_W7.62mm
C18 | C_Small | Capacitor_THT:C_Rect_L9.0mm_W2.5mm_P7.50mm_MKT | ~
U44 | MMN4116 | Package_DIP:DIP-16_W7.62mm
U45 | MMN4116 | Package_DIP:DIP-16_W7.62mm
C19 | C_Small | Capacitor_THT:C_Rect_L9.0mm_W2.5mm_P7.50mm_MKT | ~
U46 | MMN4116 | Package_DIP:DIP-16_W7.62mm
U47 | MMN4116 | Package_DIP:DIP-16_W7.62mm
C20 | C_Small | Capacitor_THT:C_Rect_L9.0mm_W2.5mm_P7.50mm_MKT | ~
U48 | MMN4116 | Package_DIP:DIP-16_W7.62mm
C21 | C_Small | Capacitor_THT:C_Rect_L9.0mm_W2.5mm_P7.50mm_MKT | ~
U50 | MMN4116 | Package_DIP:DIP-16_W7.62mm
U24 | MMN4116 | Package_DIP:DIP-16_W7.62mm
C9 | C_Small | Capacitor_THT:C_Rect_L9.0mm_W2.5mm_P7.50mm_MKT | ~
U25 | MMN4116 | Package_DIP:DIP-16_W7.62mm
C10 | C_Small | Capacitor_THT:C_Rect_L9.0mm_W2.5mm_P7.50mm_MKT | ~
U26 | MMN4116 | Package_DIP:DIP-16_W7.62mm
U27 | MMN4116 | Package_DIP:DIP-16_W7.62mm
C11 | C_Small | Capacitor_THT:C_Rect_L9.0mm_W2.5mm_P7.50mm_MKT | ~
U28 | MMN4116 | Package_DIP:DIP-16_W7.62mm
U29 | MMN4116 | Package_DIP:DIP-16_W7.62mm
C12 | C_Small | Capacitor_THT:C_Rect_L9.0mm_W2.5mm_P7.50mm_MKT | ~
U30 | MMN4116 | Package_DIP:DIP-16_W7.62mm
U31 | MMN4116 | Package_DIP:DIP-16_W7.62mm
C13 | C_Small | Capacitor_THT:C_Rect_L9.0mm_W2.5mm_P7.50mm_MKT | ~
U41 | 74LS157 | Package_DIP:DIP-16_W7.62mm | http://www.ti.com/lit/gpn/sn74LS157
U58 | 74LS157 | Package_DIP:DIP-16_W7.62mm | http://www.ti.com/lit/gpn/sn74LS157
R30 | R_Small |  | ~
R28 | R_Small |  | ~
R29 | R_Small |  | ~
R40 | R_Small |  | ~
R37 | R_Small |  | ~
R36 | R_Small |  | ~
R39 | R_Small |  | ~
R481 | R_Small |  | ~
R24 | R_Small |  | ~
R31 | R_Small |  | ~
R32 | R_Small |  | ~
R26 | R_Small |  | ~
R25 | R_Small |  | ~
R34 | R_Small |  | ~
R33 | R_Small |  | ~
R42 | R_Small |  | ~
R41 | R_Small |  | ~
U49 | MMN4116 | Package_DIP:DIP-16_W7.62mm
C26 | C_Small | Capacitor_THT:C_Rect_L9.0mm_W2.5mm_P7.50mm_MKT | ~
C27 | C_Small | Capacitor_THT:C_Rect_L9.0mm_W2.5mm_P7.50mm_MKT | ~
C28 | C_Small | Capacitor_THT:C_Rect_L9.0mm_W2.5mm_P7.50mm_MKT | ~
C29 | C_Small | Capacitor_THT:C_Rect_L9.0mm_W2.5mm_P7.50mm_MKT | ~
U60 | 74LS95 | Package_DIP:DIP-14_W7.62mm | http://www.ti.com/lit/gpn/sn74LS95
U57 | 74LS04 | Package_DIP:DIP-14_W7.62mm | http://www.ti.com/lit/gpn/sn74LS04
U2 | 74LS74 | Package_DIP:DIP-14_W7.62mm | 74xx/74hc_hct74.pdf
U38 | 74LS08 | Package_DIP:DIP-14_W7.62mm | http://www.ti.com/lit/gpn/sn74LS08
U21 | 74LS51 | Package_DIP:DIP-14_W7.62mm | http://www.ti.com/lit/ds/symlink/sn74ls51.pdf
U40 | 74LS10 | Package_DIP:DIP-14_W7.62mm | http://www.ti.com/lit/gpn/sn74LS10
U61 | 74LS74 | Package_DIP:DIP-14_W7.62mm | 74xx/74hc_hct74.pdf
CVR1 | 390p |  | ~
CCC1 | 390p |  | ~
CCS1 | 150p |  | ~
R35 | 680 |  | ~
R38 | 680 |  | ~
Y1 | 14MHz |  | ~
C30 | 15p |  | ~
C24 | 220p |  | ~
U12 | 74LS193 | Package_DIP:DIP-16_W7.62mm | http://www.ti.com/lit/ds/symlink/sn74ls193.pdf
U13 | 74LS193 | Package_DIP:DIP-16_W7.62mm | http://www.ti.com/lit/ds/symlink/sn74ls193.pdf
U32 | 74LS193 | Package_DIP:DIP-16_W7.62mm | http://www.ti.com/lit/ds/symlink/sn74ls193.pdf
U33 | 74LS193 | Package_DIP:DIP-16_W7.62mm | http://www.ti.com/lit/ds/symlink/sn74ls193.pdf
U15 | 74LS74 | Package_DIP:DIP-14_W7.62mm | 74xx/74hc_hct74.pdf
U51 | 74LS157 | Package_DIP:DIP-16_W7.62mm | http://www.ti.com/lit/gpn/sn74LS157
U39 | 74LS153 | Package_DIP:DIP-16_W7.62mm | http://www.ti.com/lit/gpn/sn74LS153
U22 | 74LS153 | Package_DIP:DIP-16_W7.62mm | http://www.ti.com/lit/gpn/sn74LS153
U20 | 74LS153 | Package_DIP:DIP-16_W7.62mm | http://www.ti.com/lit/gpn/sn74LS153
U3 | 74LS153 | Package_DIP:DIP-16_W7.62mm | http://www.ti.com/lit/gpn/sn74LS153
R7 | 33 | Resistor_THT:R_Axial_DIN0207_L6.3mm_D2.5mm_P10.16mm_Horizontal | ~
R8 | 33 |  | ~
R2 | 33 |  | ~
R3 | 33 |  | ~
R5 | 33 |  | ~
R4 | 33 |  | ~
R1 | 33 |  | ~
U4 | MMN4116 | Package_DIP:DIP-16_W7.62mm
R18 | 33 |  | ~
R21 | 33 |  | ~
R19 | 33 |  | ~
C1 | 100n | Cobra_original:C_THT_762_254 | ~
U5 | MMN4116 | Package_DIP:DIP-16_W7.62mm
U6 | MMN4116 | Package_DIP:DIP-16_W7.62mm
C2 | 100n | Cobra_original:C_THT_762_254 | ~
U7 | MMN4116 | Package_DIP:DIP-16_W7.62mm
U8 | MMN4116 | Package_DIP:DIP-16_W7.62mm
C3 | 100n | Cobra_original:C_THT_762_254 | ~
U9 | MMN4116 | Package_DIP:DIP-16_W7.62mm
U10 | MMN4116 | Package_DIP:DIP-16_W7.62mm
U11 | MMN4116 | Package_DIP:DIP-16_W7.62mm
U76 | P8212 | Package_DIP:DIP-24_W15.24mm
C4 | 100n | Cobra_original:C_THT_762_254 | ~
R23 | 33 |  | ~
R22 | 33 |  | ~
R20 | 33 |  | ~
C7 | 100n | Cobra_original:C_THT_762_254 | ~
C17 | 100n | Cobra_original:C_THT_762_254 | ~
C23 | 100n | Cobra_original:C_THT_762_254 | ~
C32 | 100n | Cobra_original:C_THT_762_254 | ~
U78 | 74LS95 | Package_DIP:DIP-14_W7.62mm | http://www.ti.com/lit/gpn/sn74LS95
U82 | 74LS95 | Package_DIP:DIP-14_W7.62mm | http://www.ti.com/lit/gpn/sn74LS95
U83 | 74LS95 | Package_DIP:DIP-14_W7.62mm | http://www.ti.com/lit/gpn/sn74LS95
U77 | 74LS95 | Package_DIP:DIP-14_W7.62mm | http://www.ti.com/lit/gpn/sn74LS95
U81 | 74LS95 | Package_DIP:DIP-14_W7.62mm | http://www.ti.com/lit/gpn/sn74LS95
U88 | 74LS86 | Package_DIP:DIP-14_W7.62mm | 74xx/74ls86.pdf
R441 | 360 |  | ~
C42 | 220u |  | ~
R431 | 4K7 |  | ~
U87 | 74LS00 | Package_DIP:DIP-14_W7.62mm | http://www.ti.com/lit/gpn/sn74ls00
C80 | ?p |  | ~
U80 | 74LS157 | Package_DIP:DIP-16_W7.62mm | http://www.ti.com/lit/gpn/sn74LS157
U85 | 74LS157 | Package_DIP:DIP-16_W7.62mm | http://www.ti.com/lit/gpn/sn74LS157
DBR1 | 1N4148 | Diode_THT:D_DO-35_SOD27_P7.62mm_Horizontal | https://assets.nexperia.com/documents/data-sheet/1N4148_1N4448.pdf
DBR2 | 1N4148 | Diode_THT:D_DO-35_SOD27_P7.62mm_Horizontal | https://assets.nexperia.com/documents/data-sheet/1N4148_1N4448.pdf
DBR3 | 1N4148 | Diode_THT:D_DO-35_SOD27_P7.62mm_Horizontal | https://assets.nexperia.com/documents/data-sheet/1N4148_1N4448.pdf
DBR4 | 1N4148 | Diode_THT:D_DO-35_SOD27_P7.62mm_Horizontal | https://assets.nexperia.com/documents/data-sheet/1N4148_1N4448.pdf
DBR5 | 1N4148 | Diode_THT:D_DO-35_SOD27_P7.62mm_Horizontal | https://assets.nexperia.com/documents/data-sheet/1N4148_1N4448.pdf
RN1 | 240 |  | ~
R581 | 470 |  | ~
R601 | 220 |  | ~
R611 | 100 |  | ~
R591 | 1K |  | ~
D4 | 1N4148 | Diode_THT:D_DO-35_SOD27_P7.62mm_Horizontal | https://assets.nexperia.com/documents/data-sheet/1N4148_1N4448.pdf
C44 | 100u |  | ~
C45 | 10u |  | ~
R95 | 10K |  | ~
J3 | DIN-5 |  | http://www.mouser.com/ds/2/18/40_c091_abd_e-75918.pdf
R96 | 1K |  | ~
U92 | LM741 | Package_DIP:DIP-8_W7.62mm | http://www.ti.com/lit/ds/symlink/lm741.pdf
D10 | 1N4148 | Diode_THT:D_DO-35_SOD27_P7.62mm_Horizontal | https://assets.nexperia.com/documents/data-sheet/1N4148_1N4448.pdf
D9 | 1N4148 | Diode_THT:D_DO-35_SOD27_P7.62mm_Horizontal | https://assets.nexperia.com/documents/data-sheet/1N4148_1N4448.pdf
R91 | 100 |  | ~
R90 | 10K |  | ~
C89 | 100n |  | ~
C90 | 100n |  | ~
D20 | 1N4148 | Diode_THT:D_DO-35_SOD27_P7.62mm_Horizontal | https://assets.nexperia.com/documents/data-sheet/1N4148_1N4448.pdf
D8 | 1N4148 | Diode_THT:D_DO-35_SOD27_P7.62mm_Horizontal | https://assets.nexperia.com/documents/data-sheet/1N4148_1N4448.pdf
J4 | DIN-5 |  | http://www.mouser.com/ds/2/18/40_c091_abd_e-75918.pdf
R98 | 10K |  | ~
D7 | 1N4148 | Diode_THT:D_DO-35_SOD27_P7.62mm_Horizontal | https://assets.nexperia.com/documents/data-sheet/1N4148_1N4448.pdf
D6 | 1N4148 | Diode_THT:D_DO-35_SOD27_P7.62mm_Horizontal | https://assets.nexperia.com/documents/data-sheet/1N4148_1N4448.pdf
R43 | 10K |  | ~
R6 | 10K |  | ~
J2 | DB25_Male_MountingHoles | Connector_Dsub:DSUB-25_Male_Horizontal_P2.77x2.84mm_EdgePinOffset4.94mm_Housed_MountingHolesOffset7.48mm | ~
R97 | 1K |  | ~
D5 | 4V7 |  | ~
R88 | 10K |  | ~
Q1 | BC327 | Package_TO_SOT_THT:TO-92_Inline | http://www.onsemi.com/pub_link/Collateral/BC327-D.PDF
R86 | 220 |  | ~
R84 | 2K2 |  | ~
R85 | 4K7 |  | ~
R87 | 2K2 |  | ~
Q3 | BC327 | Package_TO_SOT_THT:TO-92_Inline | http://www.onsemi.com/pub_link/Collateral/BC327-D.PDF
R44 | 2K2 |  | ~
C8 | 330p |  | ~
L1 | L_Small |  | ~
D19 | 1N4148 | Diode_THT:D_DO-35_SOD27_P7.62mm_Horizontal | https://assets.nexperia.com/documents/data-sheet/1N4148_1N4448.pdf
C170 | 100n |  | ~
U86 | CDB407 | Package_DIP:DIP-14_W7.62mm
R78 | 470 |  | ~
R80 | 470 |  | ~
R82 | 470 |  | ~
R83 | 470 |  | ~
R81 | 470 |  | ~
R79 | 470 |  | ~
Q2 | 2N2219 | Package_TO_SOT_THT:TO-39-3 | http://www.onsemi.com/pub_link/Collateral/2N2219-D.PDF
R92 | 150 |  | ~
R93 | 75 |  | ~
R71 | 100 |  | ~
R76 | 100 |  | ~
R77 | 100 |  | ~

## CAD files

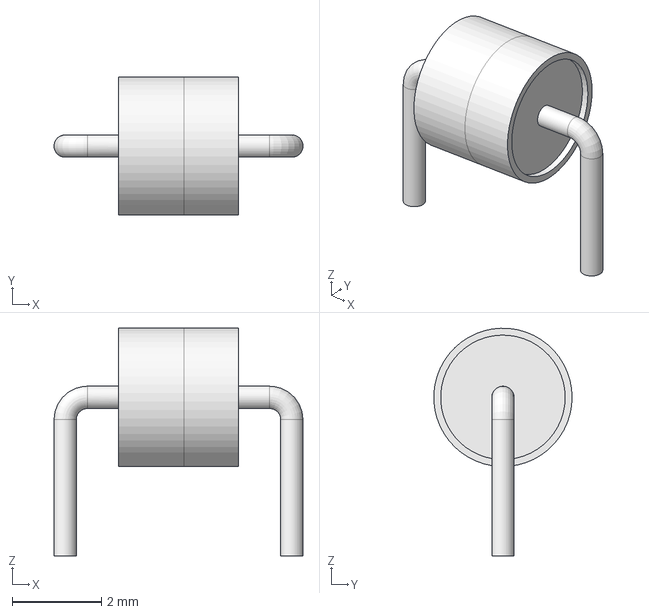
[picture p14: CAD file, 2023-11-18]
adapter/s-video/kicad/3D/C_Axial_L2.8mm_D3.1mm_P5.08mm_Horizontal.step
5.58 x 3.10 x 5.10 mm

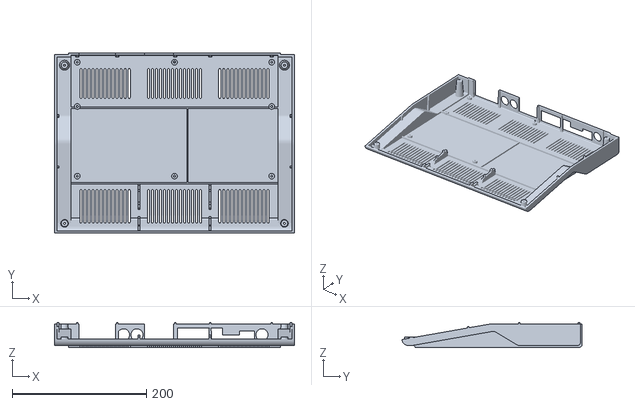
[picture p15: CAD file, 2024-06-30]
case/STL/Cobra-Case-Bottom.stl
358.0 x 269.0 x 37.5

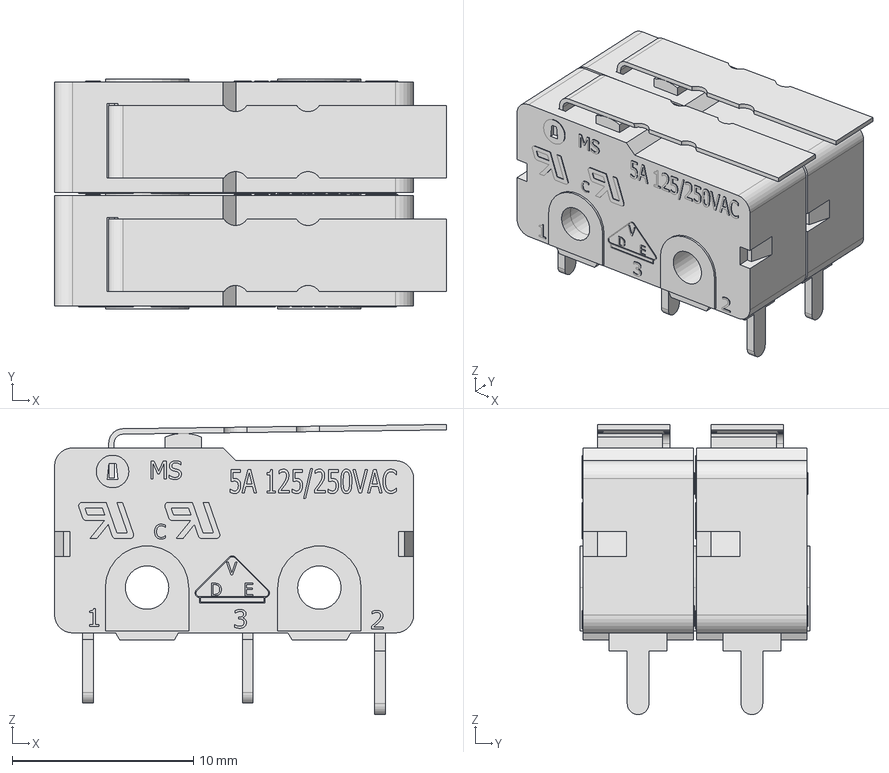
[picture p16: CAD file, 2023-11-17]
mainboard/2layer/kicad/3D/Dual_Reset.step
21.6 x 12.7 x 16.0 mm
P:\E-Switch Secure\3D_MODELS_STP_FORMAT\MS085xx02FxxxP1A.stp
P:\E-Switch Secure\3D_MODELS_STP_FORMAT\MS085xx02FxxxP1A.stp001

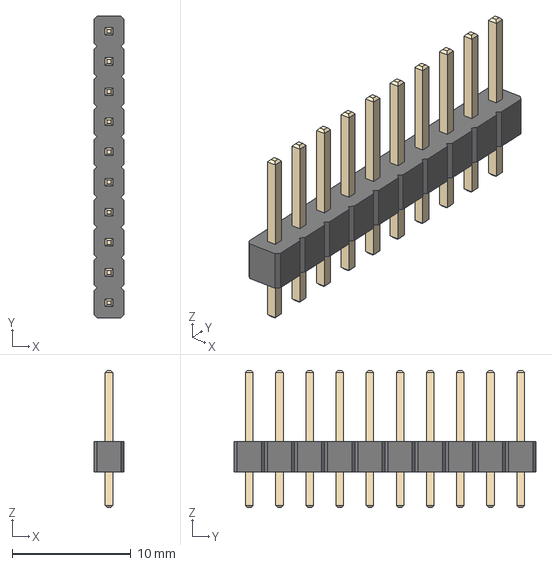
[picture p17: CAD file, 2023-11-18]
adapter/s-video/kicad/3D/PinHeader_1x10_P2.54mm_Vertical.step
2.54 x 25.4 x 11.5 mm

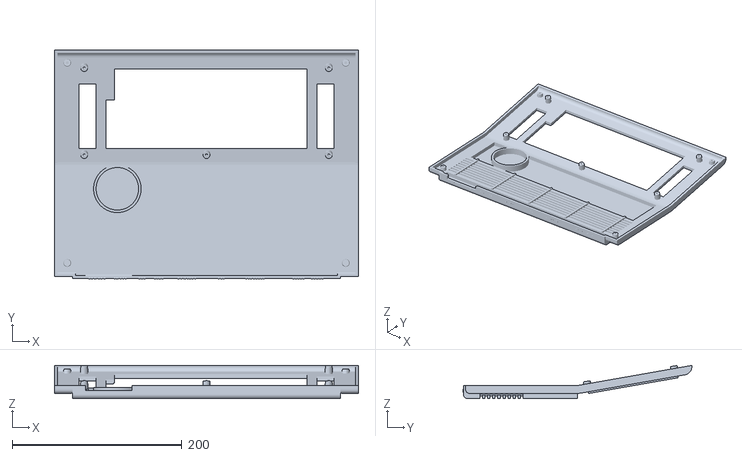
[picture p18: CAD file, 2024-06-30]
case/STL/Cobra-Case-Top.stl
358.0 x 269.3 x 39.0

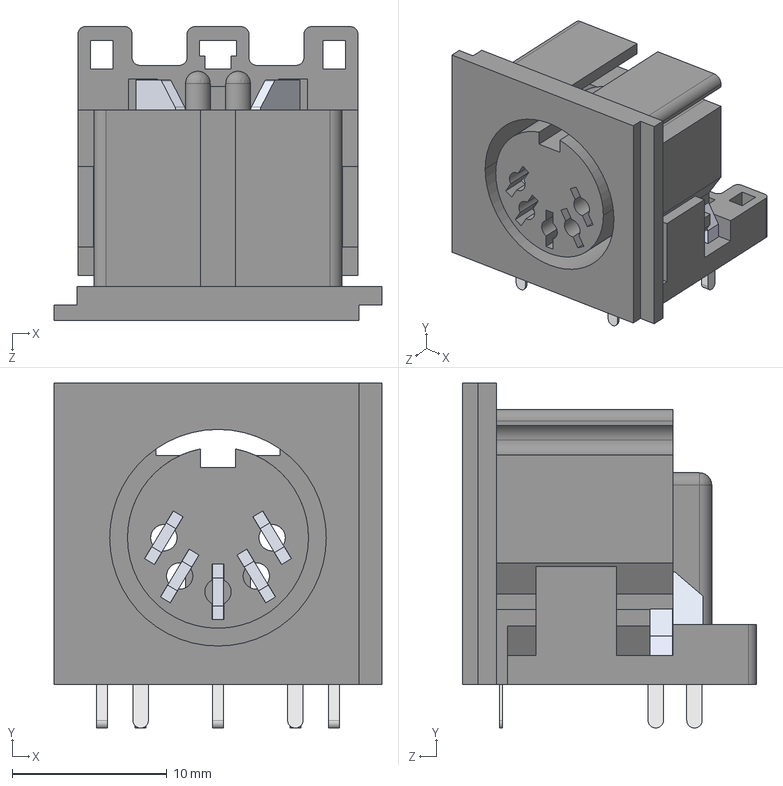
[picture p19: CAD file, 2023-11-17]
mainboard/2layer/kicad/3D/User Library-DIN-5.STEP
21.2 x 22.3 x 19.0 mm
DIN5 A
DIN5 B
DIN5 C
DIN D x 2
DIN E x 2
DIN EE x 2
DIN G
DIN DD x 2

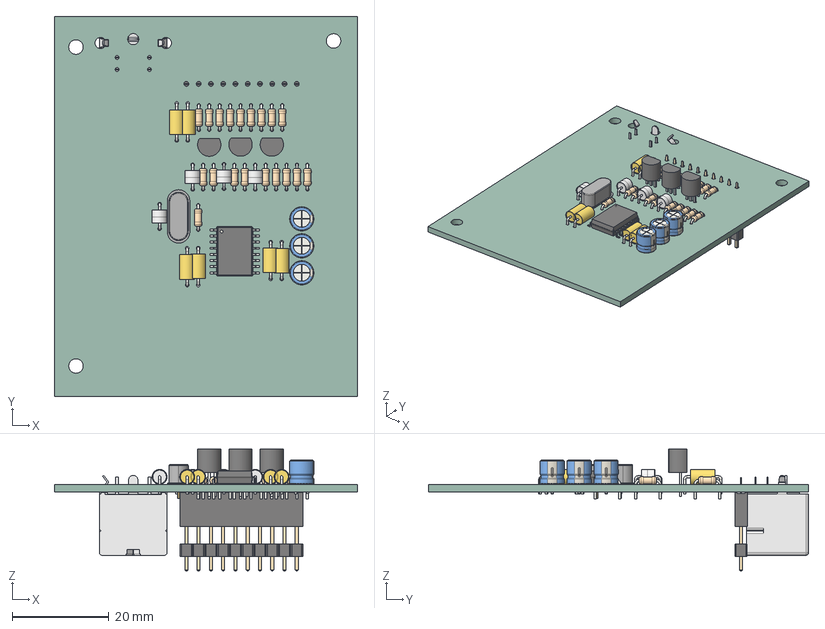
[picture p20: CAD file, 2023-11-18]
adapter/s-video/kicad/3D/svideo_board_pinheader.step
62.7 x 78.8 x 25.2 mm
PinHeader_1x10_P254mm_Vertical
_autosave-main PCB

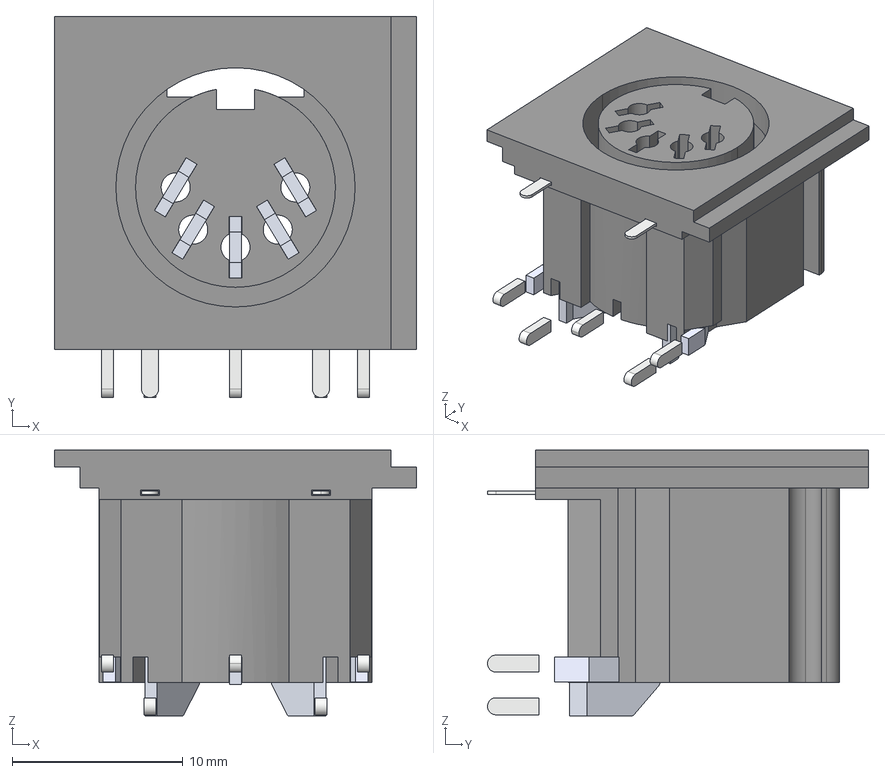
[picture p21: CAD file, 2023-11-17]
mainboard/2layer/kicad/3D/DIN-5.STEP
21.2 x 22.3 x 15.6 mm
DIN5 A
DIN5 C
DIN5 C001
DIN5 C002
DIN5 C003
DIN5 C004
DIN5 C005
DIN5 C006
DIN D x 2
DIN E x 2
DIN EE x 2
DIN G
DIN DD x 2

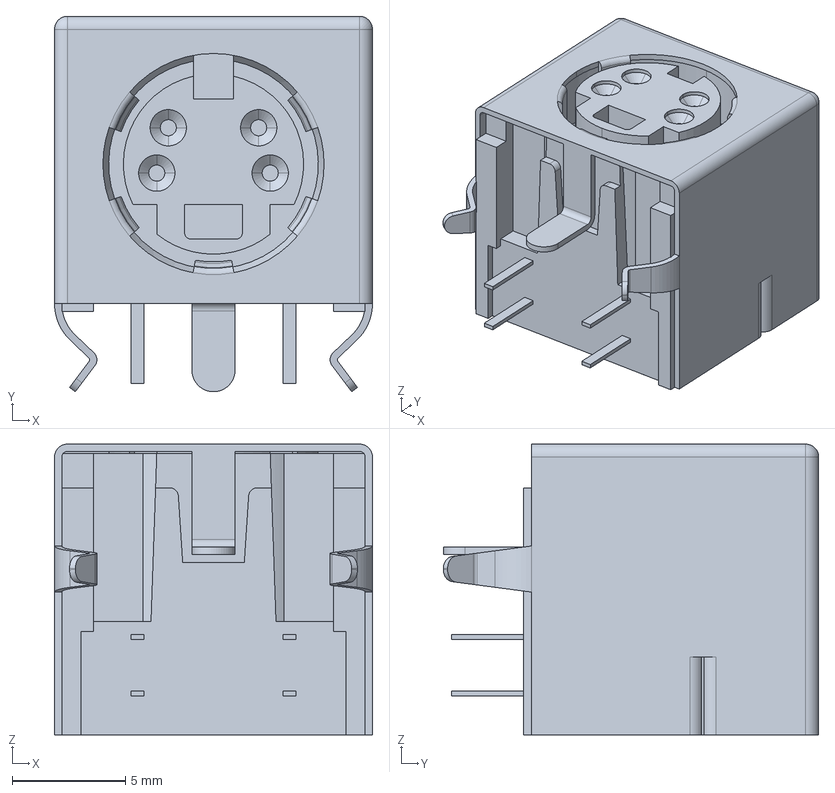
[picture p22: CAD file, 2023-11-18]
adapter/s-video/kicad/140638518-659-5749181-1/5749181-1.stp
14.0 x 16.6 x 12.8 mm

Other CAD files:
adapter/s-video/kicad/3D/svideo_board_pinheader.FCStd
mainboard/2layer/kicad/3D/DIN-5.FCStd

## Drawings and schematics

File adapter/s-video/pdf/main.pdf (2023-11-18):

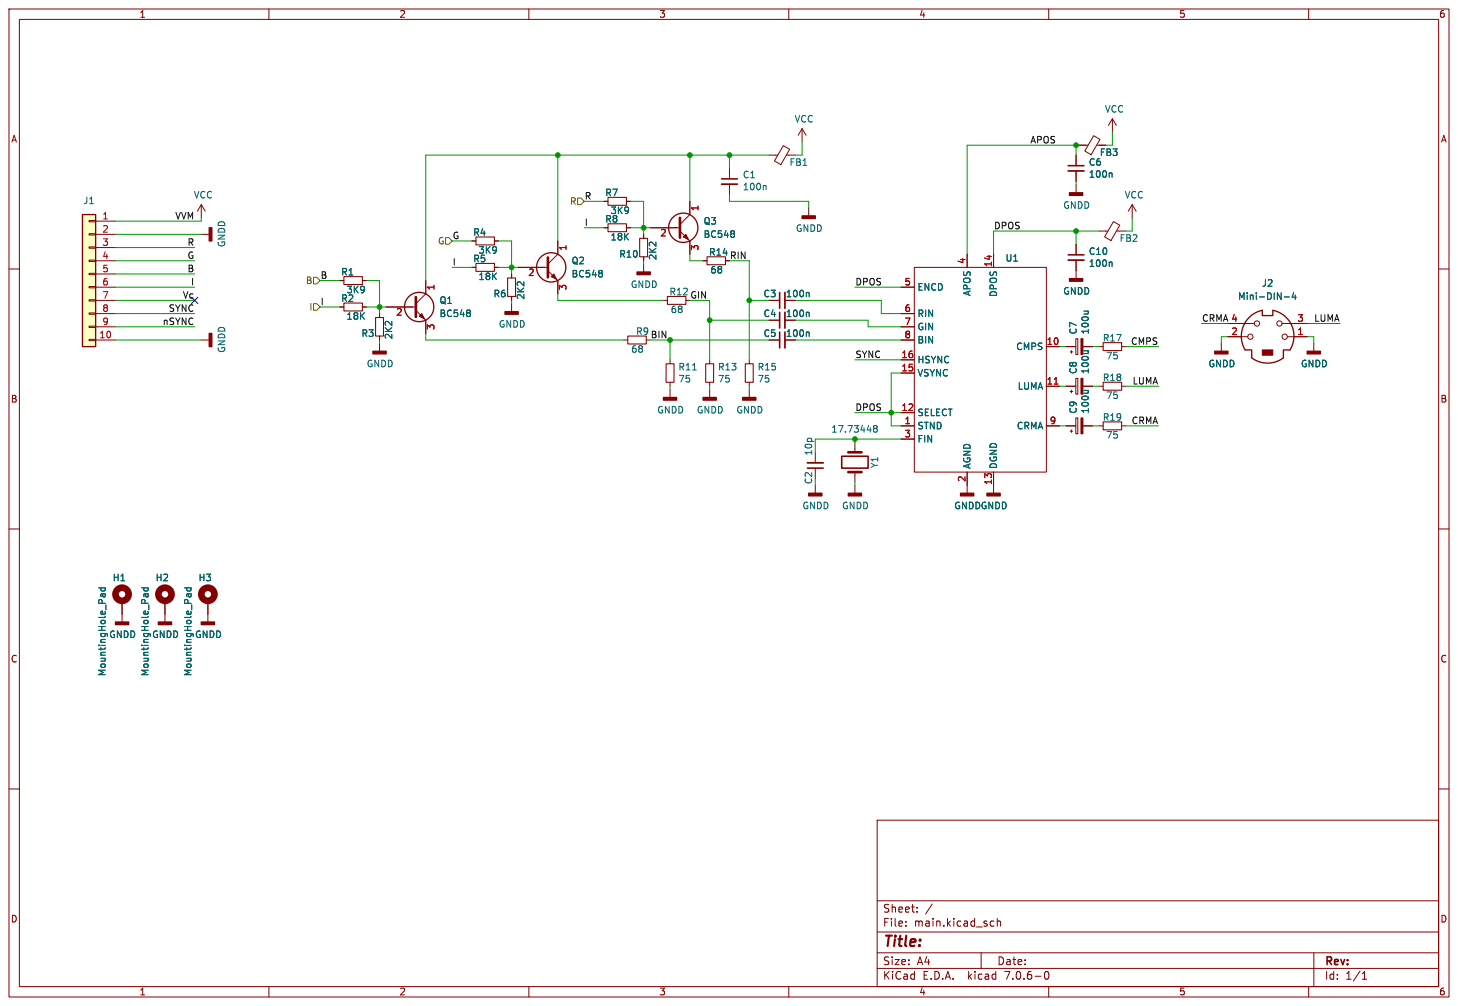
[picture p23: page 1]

4 ENCD 5 RIN 6 GIN 7 BIN 8 CRMA 9 U1 GNDD

4 ENCD 5 RIN 6 GIN 7 BIN 8 CRMA 9 GNDD

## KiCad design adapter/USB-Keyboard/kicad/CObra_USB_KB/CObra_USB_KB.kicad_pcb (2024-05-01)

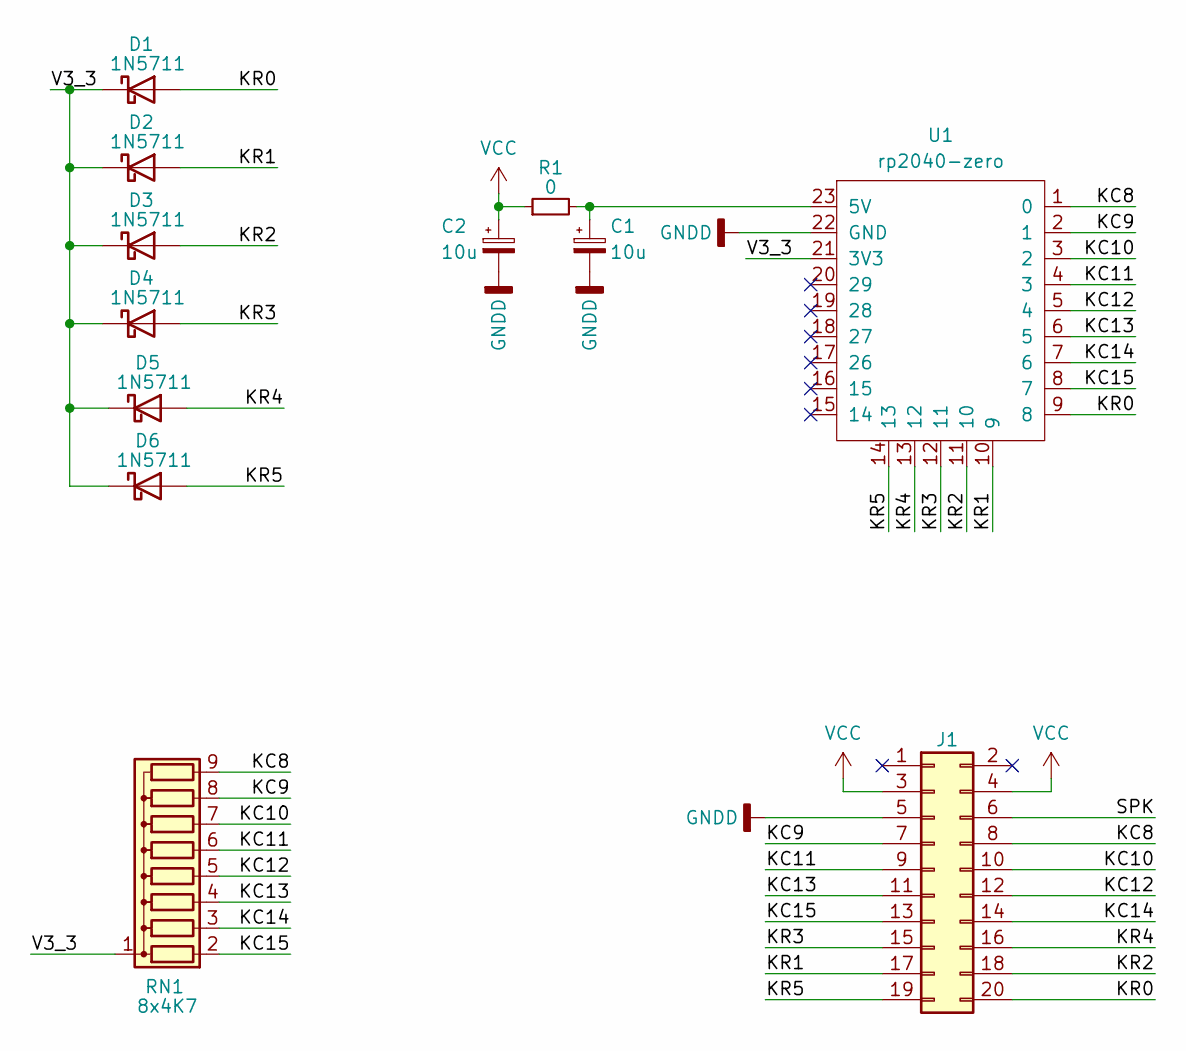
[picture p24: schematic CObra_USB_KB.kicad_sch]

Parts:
C1, C2: 10u; CP_Radial_D4.0mm_P2.00mm
D1, D2, D3, D4, D5, D6: 1N5711; D_DO-35_SOD27_P7.62mm_Horizontal
J1: Conn_02x10_Odd_Even; PinSocket_2x10_P2.54mm_Vertical
R1: 0; R_Axial_DIN0207_L6.3mm_D2.5mm_P7.62mm_Horizontal
RN1: 8x4K7; R_Array_SIP9
U1: rp2040-zero; rp2040-zero-tht

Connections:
/KC8: J1.8, RN1.9 (R8), U1.1 (0)
/KC9: J1.7, RN1.8 (R7), U1.2 (1)
/KC10: J1.10, RN1.7 (R6), U1.3 (2)
/KC11: J1.9, RN1.6 (R5), U1.4 (3)
/KC12: J1.12, RN1.5 (R4), U1.5 (4)
/KC13: J1.11, RN1.4 (R3), U1.6 (5)
/KC14: J1.14, RN1.3 (R2), U1.7 (6)
/KC15: J1.13, RN1.2 (R1), U1.8 (7)
/KR0: D1.2 (A), J1.20, U1.9 (8)
/KR1: D2.2 (A), J1.17, U1.10 (9)
/KR2: D3.2 (A), J1.18, U1.11 (10)
/KR3: D4.2 (A), J1.15, U1.12 (11)
/KR4: D5.2 (A), J1.16, U1.13 (12)
/KR5: D6.2 (A), J1.19, U1.14 (13)
/SPK: J1.6
/V3_3: D1.1 (K), D2.1 (K), D3.1 (K), D4.1 (K), D5.1 (K), D6.1 (K), RN1.1 (common), U1.21 (3V3)
GNDD: C1.2, C2.2, J1.5, U1.22 (GND)
unnamed: C1.1, R1.2, U1.23 (5V)
VCC: C2.1, J1.3, J1.4, R1.1

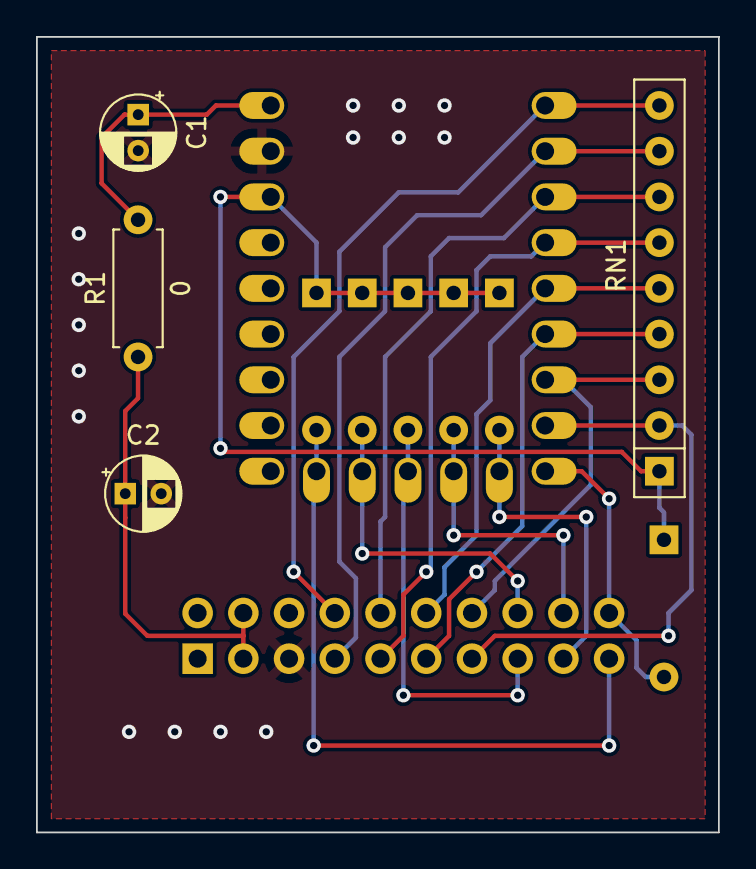
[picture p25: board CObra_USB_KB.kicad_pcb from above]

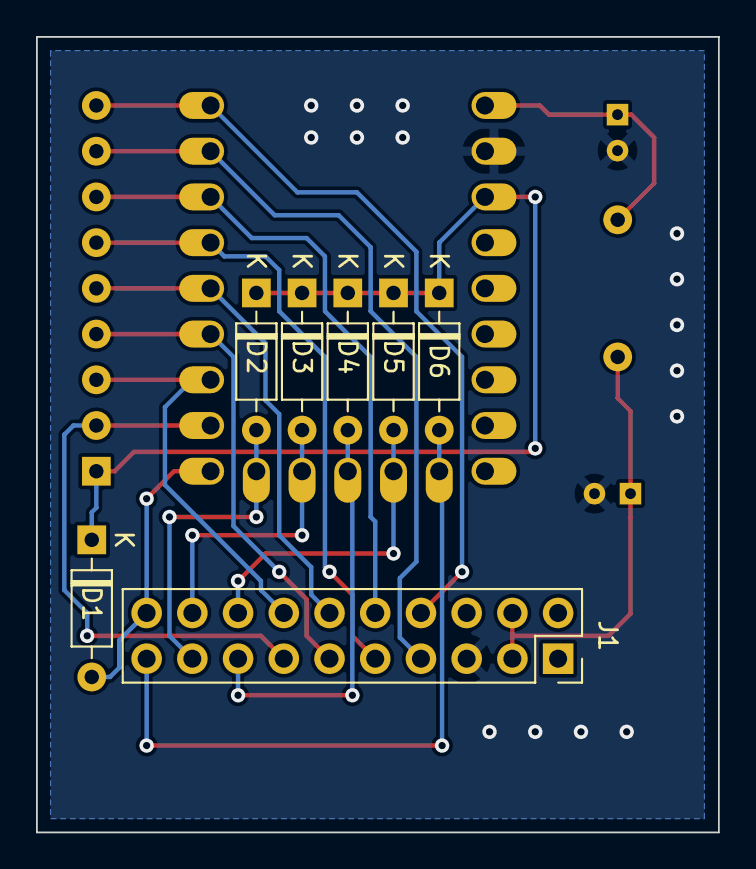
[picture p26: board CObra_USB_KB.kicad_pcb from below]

Board: 2 copper layers, 37.9 x 44.2 mm, 12 parts (7 on the bottom side), 18 nets.

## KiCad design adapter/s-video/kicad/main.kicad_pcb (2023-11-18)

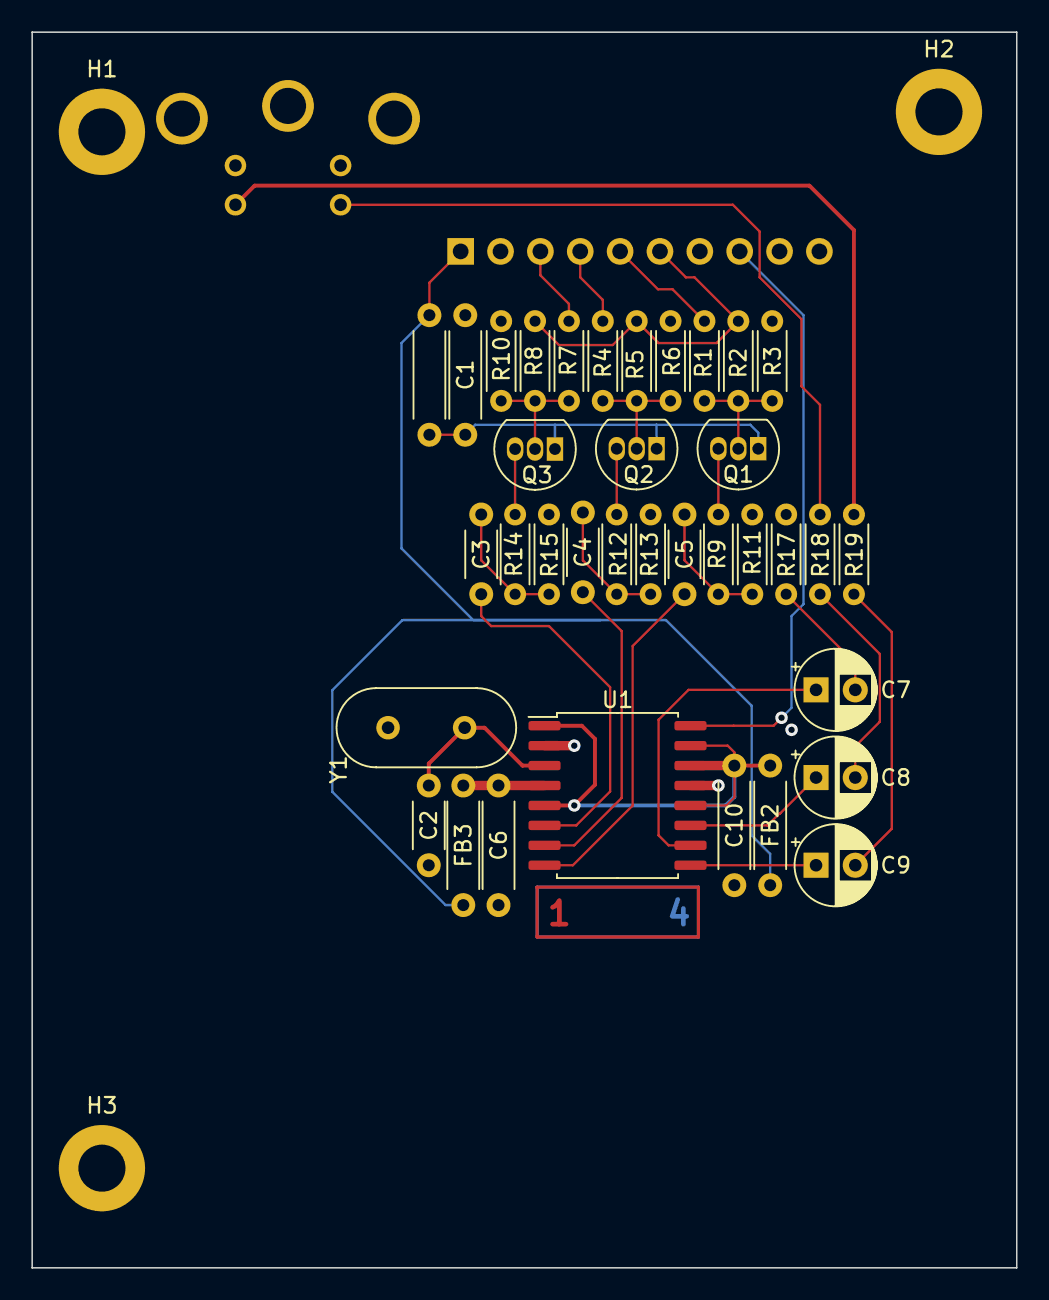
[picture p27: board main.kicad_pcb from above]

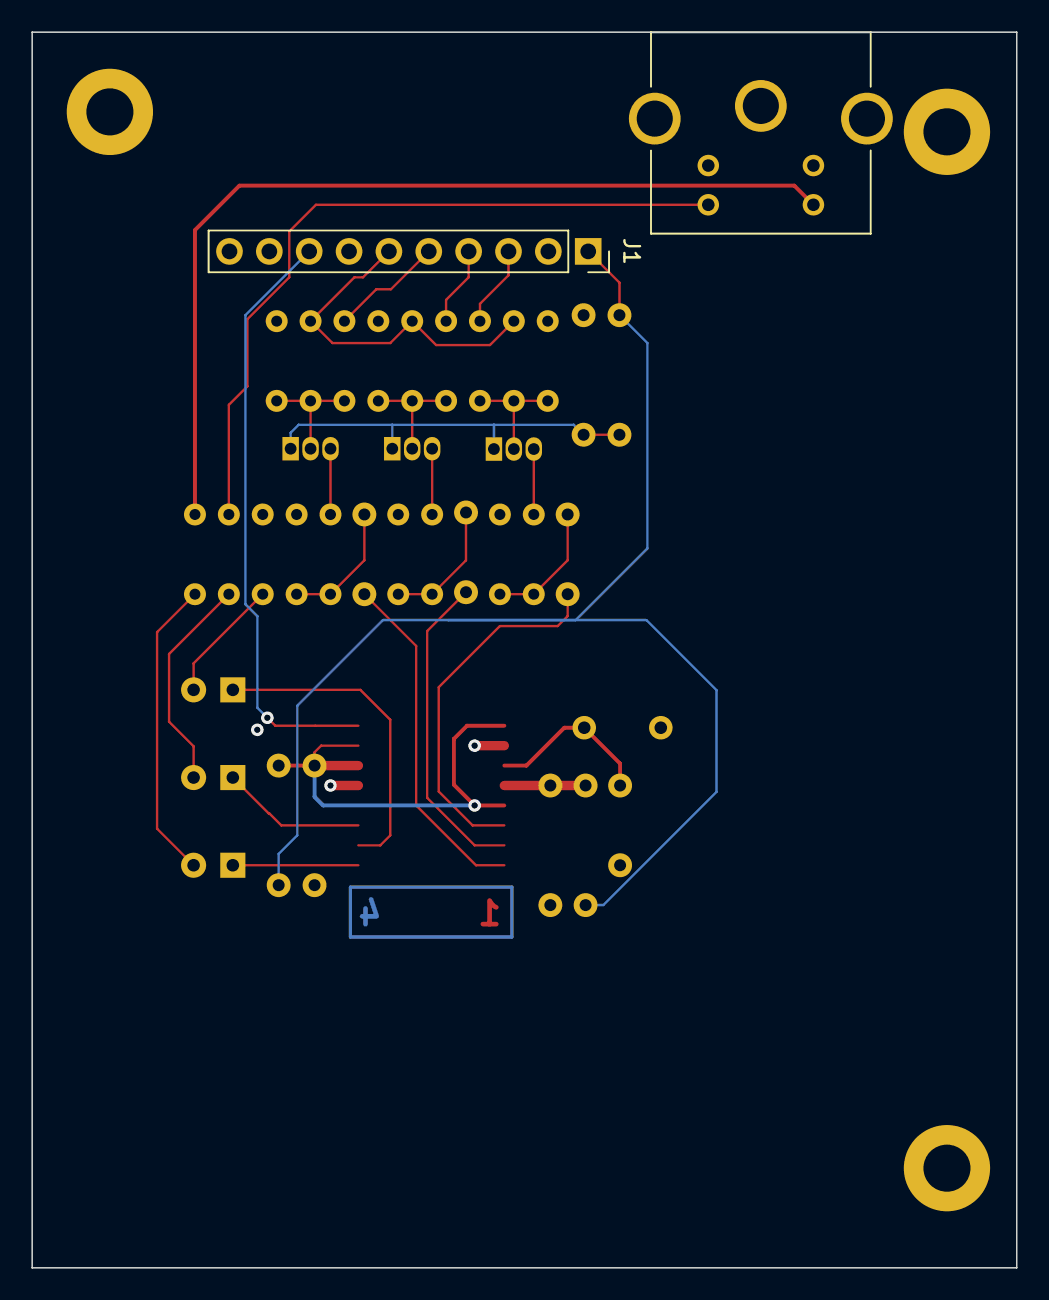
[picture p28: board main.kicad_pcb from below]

Board: 4 copper layers, 62.7 x 78.7 mm, 41 parts (2 on the bottom side), 31 nets.

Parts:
C1, C6, C10: 100n; C_THT_762_254
C2: 10p; C_THT_508_254
C3, C4, C5: 100n; C_THT_508_254
C7, C8, C9: 100u; CP_Radial_D5.0mm_P2.50mm
FB1, FB2, FB3: FerriteBead_Small; C_THT_762_254
H1, H2, H3: MountingHole_Pad; MountingHole_3mm_Pad
J1: Conn_01x10; PinSocket_1x10_P2.54mm_Vertical
J2: Mini-DIN-4; S-Video
Q1, Q2, Q3: BC548; TO-92_Inline
R1, R4, R7: 3K9; R_Axial_DIN0204_L3.6mm_D1.6mm_P5.08mm_Horizontal
R2, R5, R8: 18K; R_Axial_DIN0204_L3.6mm_D1.6mm_P5.08mm_Horizontal
R3, R6, R10: 2K2; R_Axial_DIN0204_L3.6mm_D1.6mm_P5.08mm_Horizontal
R9, R12, R14: 68; R_Axial_DIN0204_L3.6mm_D1.6mm_P5.08mm_Horizontal
R11, R13, R15, R17, R18, R19: 75; R_Axial_DIN0204_L3.6mm_D1.6mm_P5.08mm_Horizontal
U1: SOIC-16W_7.5x10.3mm_P1.27mm
Y1: 17.73448; Crystal_HC49-4H_Vertical

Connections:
/APOS: C6.1, FB3.1, U1.4 (APOS)
/B: J1.5, R1.2
/BIN: C5.1, R9.2, R11.1
/CRMA: J2.4, R19.2
/DPOS: C10.1, FB2.1, U1.1 (STND), U1.5 (ENCD), U1.12 (SELECT), U1.14 (DPOS), U1.15 (VSYNC)
/G: J1.4, R4.2
/GIN: C4.1, R12.2, R13.1
/I: J1.6, R2.2, R5.2, R8.2
/LUMA: J2.3, R18.2
/R: J1.3, R7.2
/RIN: C3.1, R14.2, R15.1
/SYNC: J1.8, U1.16 (HSYNC)
GNDD: C1.2, C2.1, C6.2, C10.2, H1.1, H2.1, H3.1, J1.2, J1.10, J2.1, J2.2, R3.1, R6.1, R10.1, R11.2, R13.2, R15.2, U1.2 (AGND), U1.13 (DGND), Y1.2
unnamed: C7.2, R17.1
unnamed: C8.2, R18.1
unnamed: C9.2, R19.1
unnamed: Q1.2 (B), R1.1, R2.1, R3.2
unnamed: C1.1, FB1.1, Q1.1 (C), Q2.1 (C), Q3.1 (C)
unnamed: Q1.3 (E), R9.1
unnamed: Q2.2 (B), R4.1, R5.1, R6.2
unnamed: Q2.3 (E), R12.1
unnamed: Q3.2 (B), R7.1, R8.1, R10.2
unnamed: Q3.3 (E), R14.1
unnamed: C5.2, U1.8 (BIN)
unnamed: C7.1, U1.10 (CMPS)
unnamed: C9.1, U1.9 (CRMA)
unnamed: C2.2, U1.3 (FIN), Y1.1
unnamed: C4.2, U1.7 (GIN)
unnamed: C8.1, U1.11 (LUMA)
unnamed: C3.2, U1.6 (RIN)
VCC: FB1.2, FB2.2, FB3.2, J1.1

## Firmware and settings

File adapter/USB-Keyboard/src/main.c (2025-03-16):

/* 
 * The MIT License (MIT)
 *
 * Copyright (c) 2019 Ha Thach (tinyusb.org)
 *
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
 */

#include <stdlib.h>
#include <stdio.h>
#include <string.h>

#include "pico/multicore.h"
#include "pico/stdlib.h"
#include "bsp/board.h"
#include "tusb.h"
//#include "cdc_app.c"
#include "hardware/clocks.h" 
#include "hardware/uart.h"

#define CLOCK_SPEED 270000

#define UART_ID uart0
#define BAUD_RATE 115200 / (CLOCK_SPEED / 133000)
//#define BAUD_RATE 76608 // 115200 for overclocking to 200000
//#define BAUD_RATE 60800 // 115200 for overclocking to 252000
//#define BAUD_RATE 115200 // 115200 for spped set to 133000

#define UART_TX_PIN 16
#define UART_RX_PIN 17



extern void cdc_app_task(void);
extern void hid_app_task(void);
extern void cobra_kb_gpio_init(void);
extern void __no_inline_not_in_flash_func(cobra_kb_type)();


int32_t kb_matrix[256] = {};
int32_t any_key = 0xFF<<8;  // TS
bool mode_E = false;

// core1_entry is confined to a dedicated bank in RAM, scratch_y
#define __core1_func(x) __scratch_y(__STRING(x)) x
void __core1_func(core1_entry)() {
    // this function performs the actual IO operation of typing on the cobra keyboard
    while (1)
      cobra_kb_type();
}

/*------------- MAIN -------------*/
int main(void)
{
  // UART
  // Set up our UART with the required speed.

  // uart_init(UART_ID, BAUD_RATE);

  // Set the TX and RX pins by using the function select on the GPIO
  // Set datasheet for more information on function select
  //gpio_set_function(UART_TX_PIN, UART_FUNCSEL_NUM(UART_ID, UART_TX_PIN));
  //gpio_set_function(UART_RX_PIN, UART_FUNCSEL_NUM(UART_ID, UART_RX_PIN));

  for(int i=0; i < 256; i++) 
    kb_matrix[i] = 0xFF<<8;

  multicore_launch_core1(core1_entry);

  board_init();
  cobra_kb_gpio_init();

  //set_sys_clock_khz(252000, true);
  set_sys_clock_khz(200000, true);

  // init host stack on configured roothub port
  tuh_init(BOARD_TUH_RHPORT);
  #define debug_printf ;
  #ifdef debug_printf
  //stdio_init_all();
  //printf("Hello World From Pi Pico UART\n");
  #endif
  
  while (1)
  {
    // tinyusb host task
    tuh_task();
    hid_app_task();
  }

  return 0;
}

//--------------------------------------------------------------------+
// TinyUSB Callbacks
//--------------------------------------------------------------------+

void tuh_mount_cb(uint8_t dev_addr)
{
  // application set-up
  #ifdef debug_printf
  printf("A device with address %d is mounted\r\n", dev_addr);
  #endif
}

void tuh_umount_cb(uint8_t dev_addr)
{
  // application tear-down
  #ifdef debug_printf
  printf("A device with address %d is unmounted \r\n", dev_addr);
  #endif
}

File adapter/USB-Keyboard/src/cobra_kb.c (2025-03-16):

/* 
 * The MIT License (MIT)
 *
 * Copyright (c) 2024 Vasile Ceteras
 *
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
 */


#include "bsp/board.h"
#include "tusb.h"
#include "pico/stdlib.h"
#include "cobra_kb.h"

#define debug_printf_not ;

uint8_t const conv_table[256][3] =  { HID_KEYCODE_TO_COBRA_KB };
uint8_t const cs_keys[7][2] = { CS_KEYS };
uint8_t const ss_keys_shift[][2] = { SS_KEYS_SHIFT };
uint8_t const ss_keys[][2] = { SS_KEYS };
uint8_t const macro_key_codes[][3] =  { FN_MACRO };

extern bool mode_E;

extern int32_t kb_matrix[256];
extern int32_t any_key;
static uint8_t lvl = 0;
//extern bool caps_lock;


void cobra_kb_set(uint8_t , uint8_t, uint8_t);
void cobra_kb_clear(uint8_t , uint8_t, uint8_t);

void key_delay (uint8_t d) {
    sleep_ms(5*d);
}

bool is_shift_on(uint8_t modifier) {
    return  (modifier & (KEYBOARD_MODIFIER_LEFTSHIFT | KEYBOARD_MODIFIER_RIGHTSHIFT));
}

bool is_cs_on(uint8_t modifier) {
    return  (modifier & (KEYBOARD_MODIFIER_LEFTALT));
}

bool is_ss_on(uint8_t modifier) {
    return  (modifier & (KEYBOARD_MODIFIER_RIGHTALT));
}

uint8_t set_kb_matrix (uint8_t key_column, int32_t set_mask){
    uint8_t index_cmp;
    for(uint8_t i = 0; i < 256; i++) {
        // check i index for <key_column> bit = 0
        index_cmp = i & (1 << key_column);
        if (index_cmp == 0) 
            kb_matrix[i] |= set_mask;
    }
}

uint8_t clear_kb_matrix (uint8_t key_column, int32_t clear_mask){
    uint8_t index_cmp;
    for(uint8_t i = 0; i < 256; i++) {
        // check i index for <key_column> bit = 0
        index_cmp = i & (1 << key_column);
        if (index_cmp == 0) 
            kb_matrix[i] &= clear_mask;
    }
}

void fill_kb_matrix() {
    uint8_t index_cmp;
    uint8_t fill_source_index;
    uint8_t fill_value;
    for (uint8_t i = 0; i < 255; i++) {
        fill_value = 0xFF;
        for (uint8_t j = 0; j < 8; j++){
            index_cmp = i & (1 << j);
            if (index_cmp == 0) {
                fill_source_index = 0xFF & ~(1 << j);
                fill_value &= (0xFF & (kb_matrix[fill_source_index]>>8));
            }
        }
        kb_matrix[i] = fill_value<<8;
    //printf("i=%d, kb120=%d \n", i, 0xFF & kb_matrix[120]>>8);
    }

}

void cobra_kb_E_mode() {
        cobra_kb_set(CS_KEYCODE, 0, 0); //CS
        cobra_kb_set(SS_KEYCODE, 0, 0); //SS for mode E
        mode_E = !mode_E;
        key_delay(5);
        cobra_kb_clear(CS_KEYCODE, 0, 0); //CS
        cobra_kb_clear(SS_KEYCODE, 0, 0); //SS for mode E
}

void cobra_macro(uint8_t key_code) {
    for(uint8_t i = 0; i < (sizeof(macro_key_codes)/sizeof(macro_key_codes[0])); i++) {
        uint8_t macro_key = macro_key_codes[i][0];
        uint8_t type_key = macro_key_codes[i][1];
        uint8_t macro_set = macro_key_codes[i][2];
        if (macro_key == key_code) {
            #ifdef debug_printf
            printf("macrokey: %02x", macro_key);
            #endif
            if (type_key !=0) {
                if (macro_set == 1)
                    cobra_kb_set(type_key, 0, 0);
                else
                    cobra_kb_clear(type_key, 0, 0);
            }
            key_delay(15);
        }
    }
        
}
uint8_t find_alternate_keycode (uint8_t keycode, uint8_t keytype) {
    uint8_t altkeycode;
    
    switch (keytype)
    {
        case 1:
          for (int i = 0; i < (sizeof(cs_keys)/(sizeof(cs_keys[0]))); i++)
            if (cs_keys[i][0] == keycode)
                altkeycode = cs_keys[i][1];
        break;
        case 2:
          for (int i = 0; i < (sizeof(ss_keys_shift)/(sizeof(ss_keys_shift[0]))); i++)
            if (ss_keys_shift[i][0] == keycode)
                altkeycode = ss_keys_shift[i][1];
        break;
        case 3:
          for (int i = 0; i < (sizeof(ss_keys)/(sizeof(ss_keys[0]))); i++)
            if (ss_keys[i][0] == keycode)
                altkeycode = ss_keys[i][1];
        break;
    }

    return altkeycode;
}
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

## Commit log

2023-11-14 Initial schematic pdf
2023-11-15 Initial commit of the original 2 layers Kicad project
    [BomTemplate.xls, Interface.kicad_sch, Interface.sch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]
2023-11-15 Changed floppy connector, fixed some library paths
    [Z80_CPU.kicad_sch]
2023-11-15 Update schematic pdf
2023-11-15 Another update to schematic pdf
2023-11-15 Fix resistor values on video memory page
    [Video_memory.kicad_sch]
2023-11-16 prototype board photo
2023-11-16 Fixed some resistor values
    [Z80_CPU.kicad_sch]
2023-11-16 Fixes for PCB DRC: trace clearance, footprints, board edges
    [Interface.kicad_sch, Memory_arbiter_cmd.kicad_sch, RAM_48.kicad_sch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]
2023-11-16 modified footprint files
2023-11-17 Added 3D symbol for DIN-5, plus some silskreen cleanup
    [DIN-5.FCStd, DIN-5.STEP, User Library-DIN-5.STEP]
2023-11-17 More fixes after running DRC. Silskcreen overlaps, other warnings
    [Dual_Reset.step, Memory_arbiter_cmd.kicad_sch]
2023-11-17 Fabrication outputs: gerber, drill, bom added
    [main-B_Cu.gbr, main-B_Mask.gbr, main-B_Paste.gbr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]
2023-11-18 s-video board
    [5749181-1.stp, C_Axial_L2.8mm_D3.1mm_P5.08mm_Horizontal.step, PinHeader_1x10_P2.54mm_Vertical.step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]
2023-11-27 Interactive BOM file added
2023-11-29 removed mounting holes and H1,H3 placeholders from the BOM/ibom, align C25 on PCB
    [Z80_CPU.kicad_sch]
2023-12-20 update U14 symbol name to 74LS10
    [Video_address_gen.kicad_sch, main.csv]
2023-12-21 changed mounting holes to 3mm, new gerbers
    [main-B_Cu.gbr, main-B_Mask.gbr, main-B_Paste.gbr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]
2024-01-12 some cleanup
    [ROM.kicad_sch]
2024-05-01 RP2040 Zero based USB Keyboard adapter
    [CObra_USB_KB.kicad_pcb, CObra_USB_KB.kicad_sch]
2024-06-28 update to latest changes in mainboard schematic
    [ROM.kicad_sch]
2024-06-28 usb keyboard adapter schematic
2024-06-30 case folder
    [Cobra-Case-Bottom.stl, Cobra-Case-Top.stl]
2024-06-30 case readme change
2024-06-30 case readme changes
2024-06-30 moved folders around
    [5749181-1.stp, C_Axial_L2.8mm_D3.1mm_P5.08mm_Horizontal.step, PinHeader_1x10_P2.54mm_Vertical.step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]
2024-09-22 New pcb photo
2025-03-16 fixes for usb keyboad adapter
    [CObra_USB_KB.kicad_pcb, CObra_USB_KB.kicad_sch]

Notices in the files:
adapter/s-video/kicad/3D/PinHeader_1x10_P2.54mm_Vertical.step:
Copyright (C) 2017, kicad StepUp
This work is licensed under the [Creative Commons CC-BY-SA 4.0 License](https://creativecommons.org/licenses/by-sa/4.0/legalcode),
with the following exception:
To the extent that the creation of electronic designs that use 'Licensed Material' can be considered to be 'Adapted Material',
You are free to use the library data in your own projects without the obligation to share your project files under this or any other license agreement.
